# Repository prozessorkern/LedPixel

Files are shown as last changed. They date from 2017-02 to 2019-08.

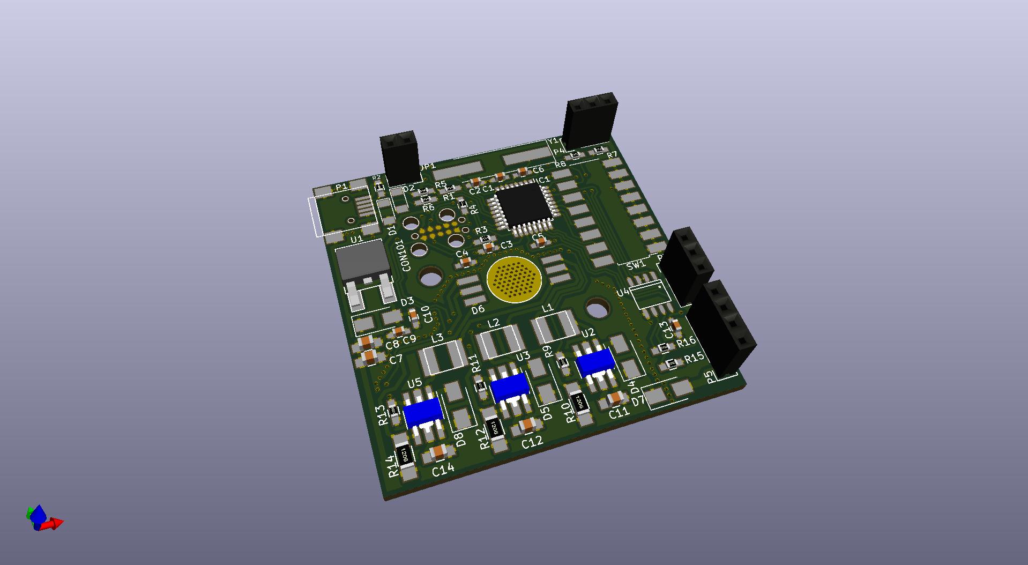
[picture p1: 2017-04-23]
atmega8/pcb/led_pixel/doc/led_pixel.jpg

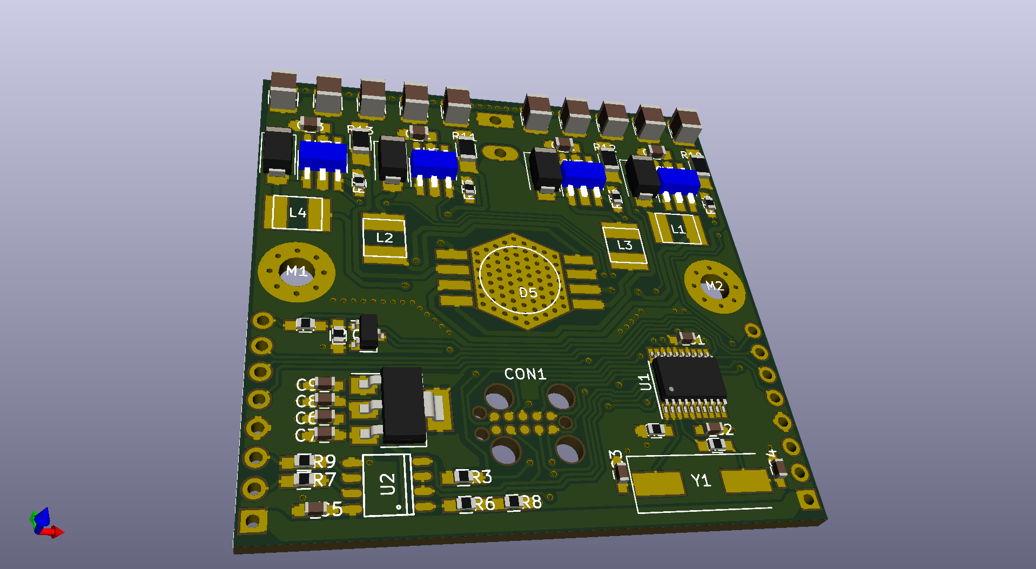
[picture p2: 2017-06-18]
stm32f030/pcb/led_pixel_stm32f030/doc/led_pixel_stm32f030.png

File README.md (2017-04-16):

# LedPixel
Small devices to drive up to 10W RGB LEDs by DMX
There might be a possibility to use them als a LED Wall/Display with extreme high power :)

## there might be several versions of the pcb (and Firmware)
* a dev board version with an ATmega8 with USB Bootloader, a dip Switch and some additional Interfaces
* a RGBW version with 4 LED Drivers an a STM32 Controller with 16 bit PWM, an faster RS485 than DMX and an additional SPI Interface for addressing multiple devices
* a board for an external LED

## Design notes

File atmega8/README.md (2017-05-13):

# LedPixel atmega8

* a dev board version with an ATmega8 with USB Bootloader, a dip Switch and some additional Interfaces
* designed to drive a 10W RGB LED with a single supply and DMX

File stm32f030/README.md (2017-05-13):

# LedPixel stm32f030

* a more powerful version with 4 chanels for RGBW LEDs
* designed with a backplane bus for dynamic adressing of multiple devices
* capable of 16 bit pwm for better resolution

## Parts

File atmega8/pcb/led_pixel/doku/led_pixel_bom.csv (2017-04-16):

ID | Bezeichner | Gehäuse | Stückzahl | Bezeichnung | Anbieter und Ref.
1 | Y1 | Crystal_SMD_HC49-SD_HandSoldering | 1 | CRYSTAL
2 | L3,L2,L1 | Choke_SMD_4.5x4x3.2 | 3 | 68u
3 | D6 | LED_SMD_RGB_3W | 1 | LED_RGB
4 | REF**,REF** | MountingHole_3.2mm_M3_DIN965 | 2 | MountingHole_3.2mm_M3_DIN965
5 | REF*** | OSHW-Logo2_7.3x6mm_Copper | 1 | OSHW-Logo2_7.3x6mm_Copper
6 | REF*** | WEEE-Logo_4.2x6mm_SilkScreen | 1 | WEEE-Logo_4.2x6mm_SilkScreen
7 | REF** | Symbol_KiCAD-Logo_CopperAndSilkScreenTop | 1 | KiCAD Logo
8 | G*** | Shimatta_SolderMask | 1 | LOGO
9 | C1,C2 | C_0603_HandSoldering | 2 | 22p
10 | C3,C10 | C_0603_HandSoldering | 2 | 1u
11 | C4,C5,C6,C9,C13 | C_0603_HandSoldering | 5 | 100n
12 | C7 | C_0805_HandSoldering | 1 | 1u
13 | C8,C11,C12,C14 | C_0805_HandSoldering | 4 | 100n
14 | IC1 | TQFP-32_7x7mm_Pitch0.8mm | 1 | ATMEGA8-AI
15 | P1 | USB_Mini-B | 1 | USB_OTG
16 | R1,R9,R11,R13,R4 | R_0603_HandSoldering | 5 | 10k
17 | R2 | R_0603_HandSoldering | 1 | 2k2
18 | R3,R7,R8,R15,R16 | R_0603_HandSoldering | 5 | 10
19 | R5,R6 | R_0603_HandSoldering | 2 | 39
20 | R10,R12,R14 | R_1206_HandSoldering | 3 | 0.33
21 | U1 | TO-252-2Lead | 1 | MC78M05CDT
22 | JP1 | Socket_Strip_Straight_1x02 | 1 | Bootloader
23 | P3,P4 | Socket_Strip_Straight_1x03 | 2 | CONN_01X03
24 | P5 | Socket_Strip_Straight_1x04 | 1 | CONN_01X04
25 | U2,U3,U5 | SOT89-5_Housing_Handsoldering | 3 | PT4115
26 | U4 | SO-8 | 1 | SN75176
27 | SW1 | SW_DIP_x8_SMD_2.54 | 1 | SW_DIP_x08
28 | D1,D2 | D_MiniMELF_Standard | 2 | 3V3
29 | D3,D4,D5,D7,D8 | D_SMA_Standard | 5 | SS310
30 | CON101 | TC2050-IDC | 1 | 10PIN_ISP_AVR

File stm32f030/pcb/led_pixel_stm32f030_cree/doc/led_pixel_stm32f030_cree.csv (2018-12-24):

ID | Bezeichner | Gehäuse | Stückzahl | Bezeichnung | Anbieter und Referenz
1 | CON1 | TC2050-IDC | 1 | 10PIN_JTAG_SWD
2 | G*** | Shimatta_SolderMask | 1 | LOGO
3 | REF*** | ESD-Logo_8.9x8mm_SilkScreen | 1 | ESD-Logo_8.9x8mm_SilkScreen
4 | REF*** | WEEE-Logo_4.2x6mm_SilkScreen | 1 | WEEE-Logo_4.2x6mm_SilkScreen
5 | REF** | Symbol_KiCAD-Logo_CopperAndSilkScreenTop | 1 | KiCAD Logo
6 | L4,L1,L2,L3 | Choke_SMD_4.5x4x3.2 | 4 | 68u
7 | Q1 | SOT-23 | 1 | BC107
8 | C5,C1,C2,C7,C8 | C_0603_HandSoldering | 5 | 100n
9 | C3,C4 | C_0603_HandSoldering | 2 | 20p
10 | C6,C9 | C_0603_HandSoldering | 2 | 1u
11 | C10,C11,C12,C13 | C_0805_HandSoldering | 4 | 100n
12 | D1,D2,D3,D4 | D_SMA_Standard | 4 | SS310
13 | J1 | AK300-2 | 1 | Screw_Terminal_01x02
14 | R1,R3,R5,R8,R14,R15,R16,R17 | R_0603_HandSoldering | 8 | 10k
15 | R4 | R_0603_HandSoldering | 1 | 1k
16 | R6 | R_0603_HandSoldering | 1 | 6k8
17 | R7,R9 | R_0603_HandSoldering | 2 | 10
18 | R10,R11,R12,R13 | R_1206_HandSoldering | 4 | 0.33
19 | U1 | TSSOP-20_4.4x6.5mm_Pitch0.65mm | 1 | STM32F030F4Px
20 | U2 | SO-8 | 1 | SN75176
21 | U3 | SOT-223 | 1 | 1117-3.3
22 | U4,U5,U6,U7 | SOT89-5_Housing_Handsoldering | 4 | PT4115
23 | Y1 | Crystal_SMD_HC49-SD | 1 | 8MHz
24 | R2 | R_0603_HandSoldering | 1 | 220
25 | J2,J3 | Pin_Header_Straight_1x08_Pitch2.54mm | 2 | Conn_01x08
26 | C14,C15,C16,C17,C18,C19,C20,C21,C22,C23 | C_1210 | 10 | 10u 50V
27 | M1,M2 | MountingHole_3.2mm_M3_Pad_Via | 2 | mounting hole
28 | D5 | LED_SMD_CREE_XM-L_4Color | 1 | LED_RGBW_cree

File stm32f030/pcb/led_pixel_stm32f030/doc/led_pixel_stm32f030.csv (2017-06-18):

ID | Bezeichner | Gehäuse | Stückzahl | Bezeichnung | Anbieter und Ref.
1 | D5 | LED_SMD_RGBW_4W_ISOLATED | 1 | LED_RGBW
2 | CON1 | TC2050-IDC | 1 | 10PIN_JTAG_SWD
3 | G*** | Shimatta_SolderMask | 1 | LOGO
4 | REF*** | ESD-Logo_8.9x8mm_SilkScreen | 1 | ESD-Logo_8.9x8mm_SilkScreen
5 | REF*** | WEEE-Logo_4.2x6mm_SilkScreen | 1 | WEEE-Logo_4.2x6mm_SilkScreen
6 | REF** | Symbol_KiCAD-Logo_CopperAndSilkScreenTop | 1 | KiCAD Logo
7 | L4,L1,L2,L3 | Choke_SMD_4.5x4x3.2 | 4 | 68u
8 | Q1 | SOT-23 | 1 | BC107
9 | C5,C1,C2,C7,C8 | C_0603_HandSoldering | 5 | 100n
10 | C3,C4 | C_0603_HandSoldering | 2 | 20p
11 | C6,C9 | C_0603_HandSoldering | 2 | 1u
12 | C10,C11,C12,C13 | C_0805_HandSoldering | 4 | 100n
13 | D1,D2,D3,D4 | D_SMA_Standard | 4 | SS310
14 | J1 | AK300-2 | 1 | Screw_Terminal_1x02
15 | R1,R3,R5,R8,R14,R15,R16,R17 | R_0603_HandSoldering | 8 | 10k
16 | R4 | R_0603_HandSoldering | 1 | 1k
17 | R6 | R_0603_HandSoldering | 1 | 6k8
18 | R7,R9 | R_0603_HandSoldering | 2 | 10
19 | R10,R11,R12,R13 | R_1206_HandSoldering | 4 | 0.33
20 | U1 | TSSOP-20_4.4x6.5mm_Pitch0.65mm | 1 | STM32F030F4Px
21 | U2 | SO-8 | 1 | SN75176
22 | U3 | SOT-223 | 1 | 1117-3.3
23 | U4,U5,U6,U7 | SOT89-5_Housing_Handsoldering | 4 | PT4115
24 | Y1 | Crystal_SMD_HC49-SD | 1 | 8MHz
25 | R2 | R_0603_HandSoldering | 1 | 220
26 | J2,J3 | Pin_Header_Straight_1x08_Pitch2.54mm | 2 | CONN_01X08
27 | C14,C15,C16,C17,C18,C19,C20,C21,C22,C23 | C_1210 | 10 | 10u 50V
28 | M1,M2 | MountingHole_3.2mm_M3_Pad_Via | 2 | mounting hole

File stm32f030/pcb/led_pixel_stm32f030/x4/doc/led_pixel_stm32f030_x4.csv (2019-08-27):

Id | Designator | Package | Quantity | Designation | Supplier and ref
1 | C19,C18,C17,C16,C15,C14,C23,C22,C21,C20,C19,C18,C17,C16,C15,C14,C23,C22,C21,C20,C19,C18,C17,C16,C15,C14,C23,C22,C21,C20,C14,C15,C16,C17,C18,C19,C20,C21,C22,C23 | C_1210 | 40 | 10u 50V
2 | D5,D5,D5,D5 | LED_SMD_RGBW_4W_ISOLATED | 4 | LED_RGBW
3 | C11,C10,C12,C13,C11,C10,C12,C13,C11,C10,C12,C13,C10,C11,C12,C13 | C_0805_HandSoldering | 16 | 100n
4 | Q1,Q1,Q1,Q1 | SOT-23 | 4 | BC107
5 | C9,C6,C9,C6,C9,C6,C6,C9 | C_0603_HandSoldering | 8 | 1u
6 | M2,M1,M2,M1,M2,M1,M1,M2 | MountingHole_3.2mm_M3_Pad_Via | 8 | mounting hole
7 | R15,R5,R17,R1,R8,R16,R14,R3,R15,R5,R17,R1,R8,R16,R14,R3,R15,R5,R17,R1,R8,R16,R14,R3,R1,R3,R5,R8,R14,R15,R16,R17 | R_0603_HandSoldering | 32 | 10k
8 | D1,D2,D3,D4,D1,D2,D3,D4,D1,D2,D3,D4,D1,D2,D3,D4 | D_SMA_Standard | 16 | SS310
9 | L3,L1,L2,L4,L3,L1,L2,L4,L3,L1,L2,L4,L4,L1,L2,L3 | Choke_SMD_4.5x4x3.2 | 16 | 68u
10 | R13,R10,R11,R12,R13,R10,R11,R12,R13,R10,R11,R12,R10,R11,R12,R13 | R_1206_HandSoldering | 16 | 0.33
11 | C1,C2,C8,C7,C5,C1,C2,C8,C7,C5,C1,C2,C8,C7,C5,C5,C1,C2,C7,C8 | C_0603_HandSoldering | 20 | 100n
12 | U3,U3,U3,U3 | SOT-223 | 4 | 1117-3.3
13 | U1,U1,U1,U1 | TSSOP-20_4.4x6.5mm_Pitch0.65mm | 4 | STM32F030F4Px
14 | U4,U6,U5,U7,U4,U6,U5,U7,U4,U6,U5,U7,U4,U5,U6,U7 | SOT89-5_Housing_Handsoldering | 16 | PT4115
15 | R6,R6,R6,R6 | R_0603_HandSoldering | 4 | 6k8
16 | Y1,Y1,Y1,Y1 | Crystal_SMD_HC49-SD | 4 | 8MHz
17 | C3,C4,C3,C4,C3,C4,C3,C4 | C_0603_HandSoldering | 8 | 20p
18 | R4,R4,R4,R4 | R_0603_HandSoldering | 4 | 1k
19 | R7,R9,R7,R9,R7,R9,R7,R9 | R_0603_HandSoldering | 8 | 10
20 | J2,J3,J2,J3,J2,J3,J2,J3 | Pin_Header_Straight_1x08_Pitch2.54mm | 8 | CONN_01X08
21 | U2,U2,U2,U2 | SO-8 | 4 | SN75176
22 | R2,R2,R2,R2 | R_0603_HandSoldering | 4 | 220
23 | J1,J1,J1,J1 | AK300-2 | 4 | Screw_Terminal_1x02
24 | CON1,CON1,CON1,CON1 | TC2050-IDC | 4 | 10PIN_JTAG_SWD
25 | G*** | Shimatta_SolderMask | 1 | LOGO
26 | REF*** | ESD-Logo_8.9x8mm_SilkScreen | 1 | ESD-Logo_8.9x8mm_SilkScreen
27 | REF*** | WEEE-Logo_4.2x6mm_SilkScreen | 1 | WEEE-Logo_4.2x6mm_SilkScreen
28 | REF** | Symbol_KiCAD-Logo_CopperAndSilkScreenTop | 1 | KiCAD Logo

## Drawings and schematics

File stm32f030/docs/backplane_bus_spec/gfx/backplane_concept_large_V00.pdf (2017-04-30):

## large scale

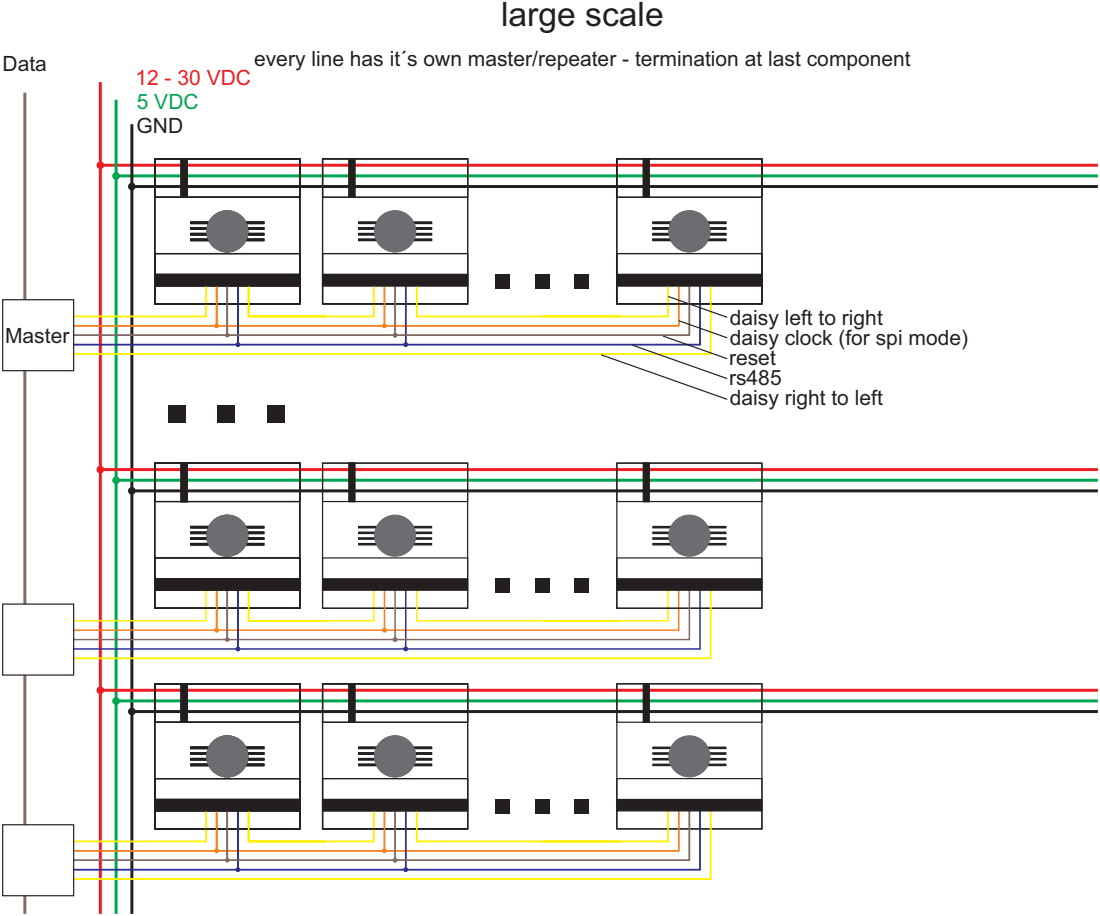
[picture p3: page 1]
12 - 30 VDC 5 VDC GND; Data; Master

every line has it´s own master/repeater - termination at last component

daisy left to right
daisy clock (for spi mode)
reset
daisy right to left

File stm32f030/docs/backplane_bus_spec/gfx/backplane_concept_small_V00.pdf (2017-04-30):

## small scale

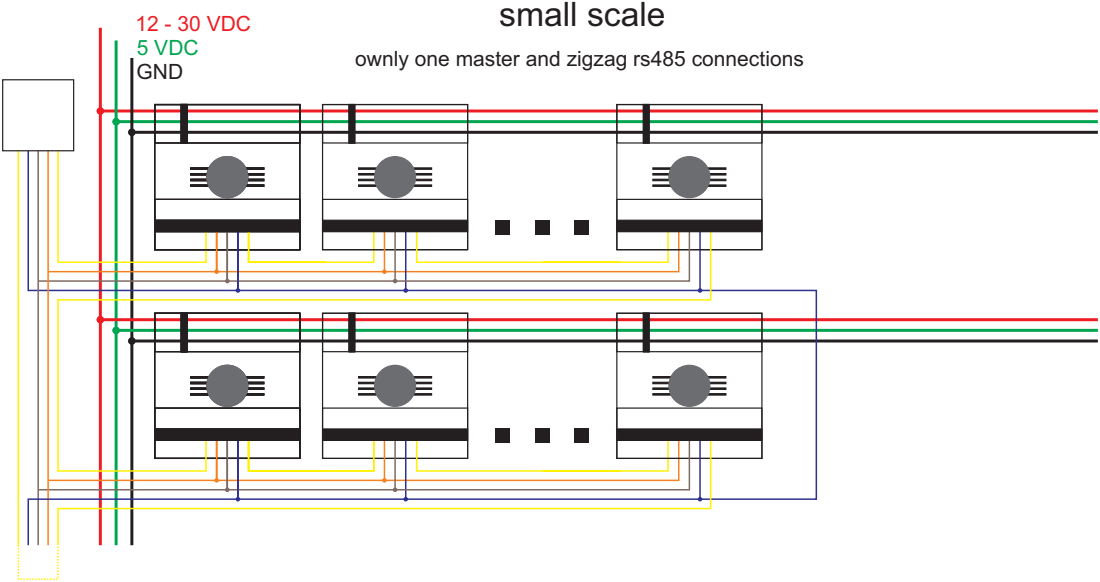
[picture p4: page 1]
12 - 30 VDC 5 VDC GND

ownly one master and zigzag rs485 connections

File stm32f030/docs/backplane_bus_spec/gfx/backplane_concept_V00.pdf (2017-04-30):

## large scale

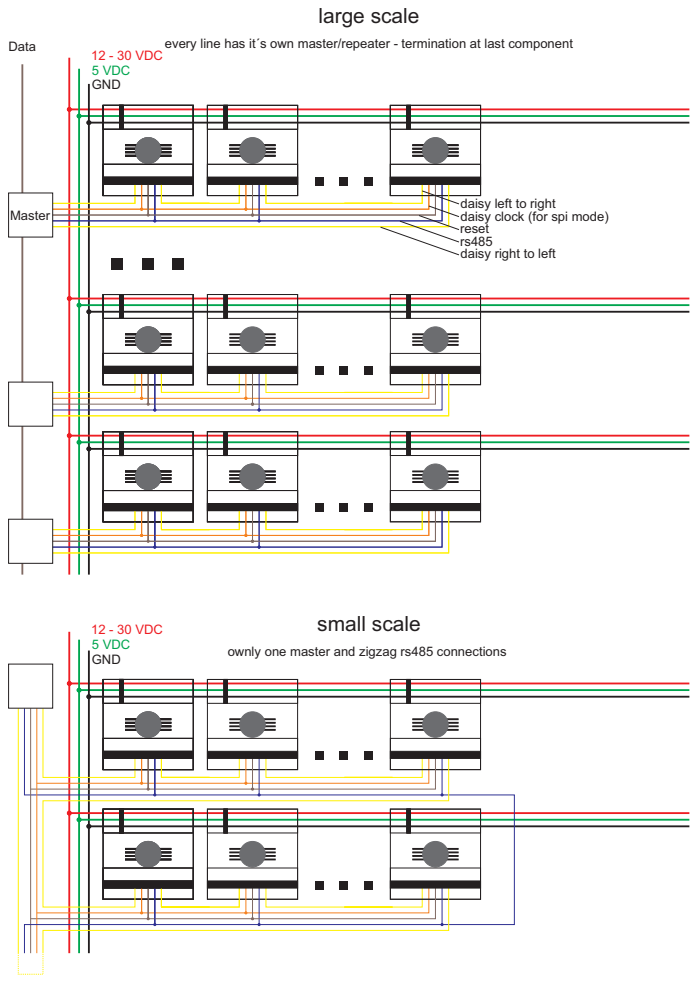
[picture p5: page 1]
12 - 30 VDC 5 VDC GND; Data; small scale; Master

every line has it´s own master/repeater - termination at last component

daisy left to right
daisy clock (for spi mode)
reset
daisy right to left

ownly one master and zigzag rs485 connections

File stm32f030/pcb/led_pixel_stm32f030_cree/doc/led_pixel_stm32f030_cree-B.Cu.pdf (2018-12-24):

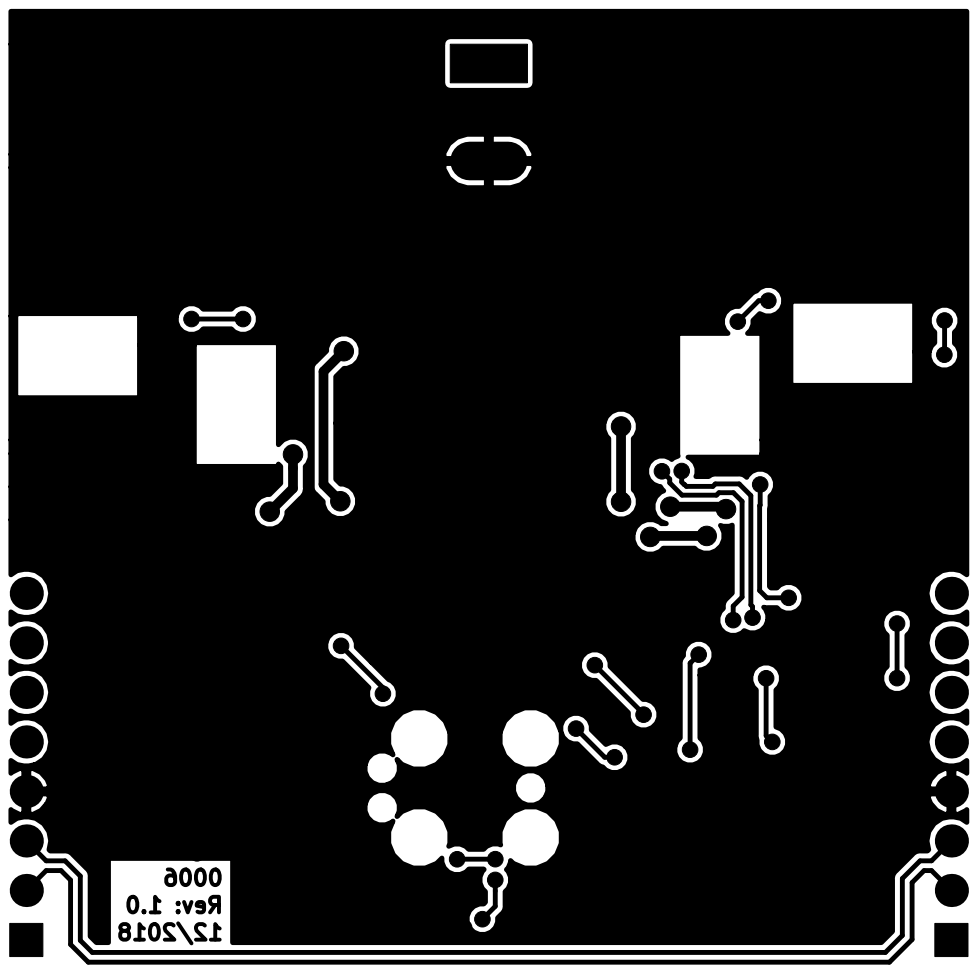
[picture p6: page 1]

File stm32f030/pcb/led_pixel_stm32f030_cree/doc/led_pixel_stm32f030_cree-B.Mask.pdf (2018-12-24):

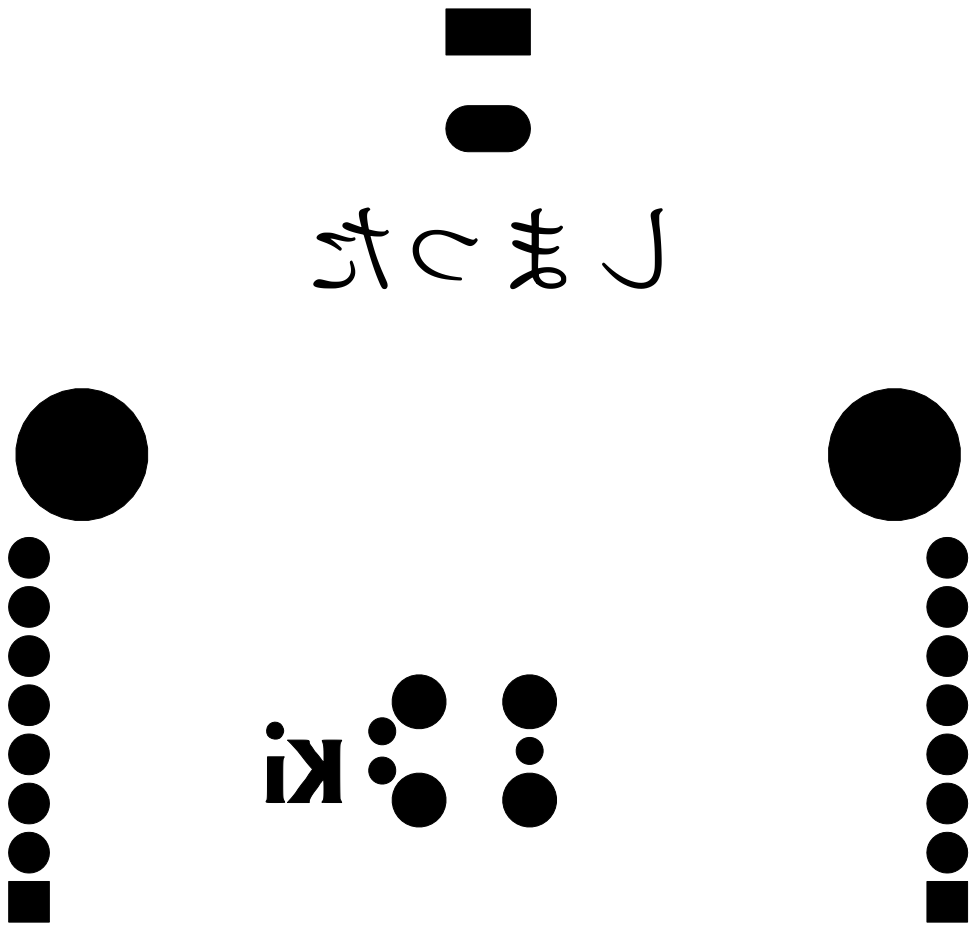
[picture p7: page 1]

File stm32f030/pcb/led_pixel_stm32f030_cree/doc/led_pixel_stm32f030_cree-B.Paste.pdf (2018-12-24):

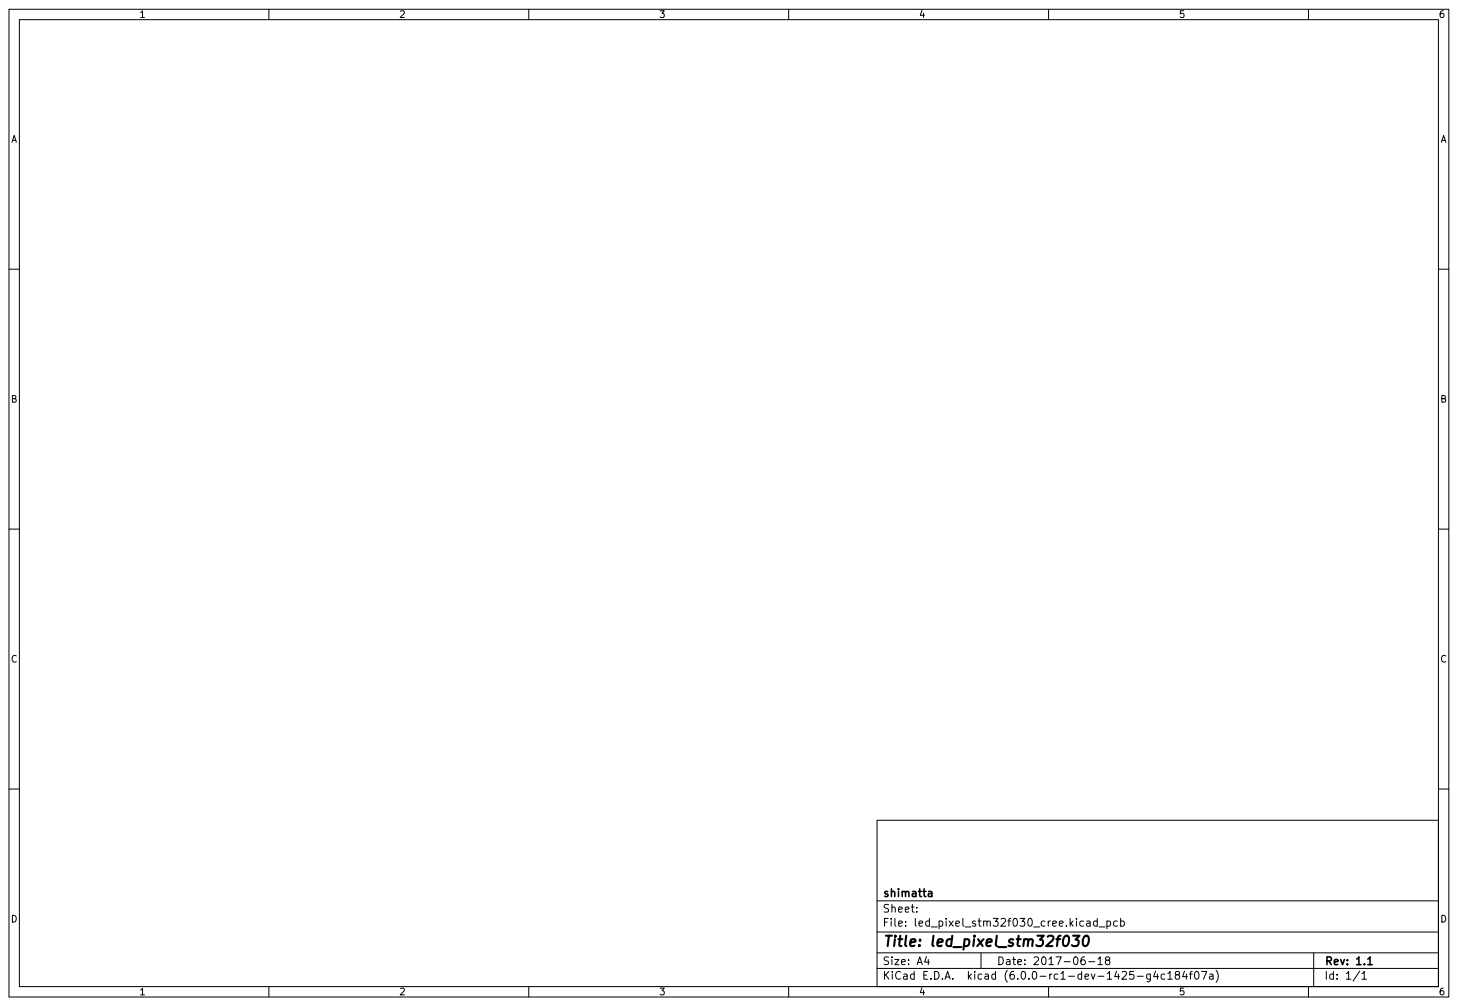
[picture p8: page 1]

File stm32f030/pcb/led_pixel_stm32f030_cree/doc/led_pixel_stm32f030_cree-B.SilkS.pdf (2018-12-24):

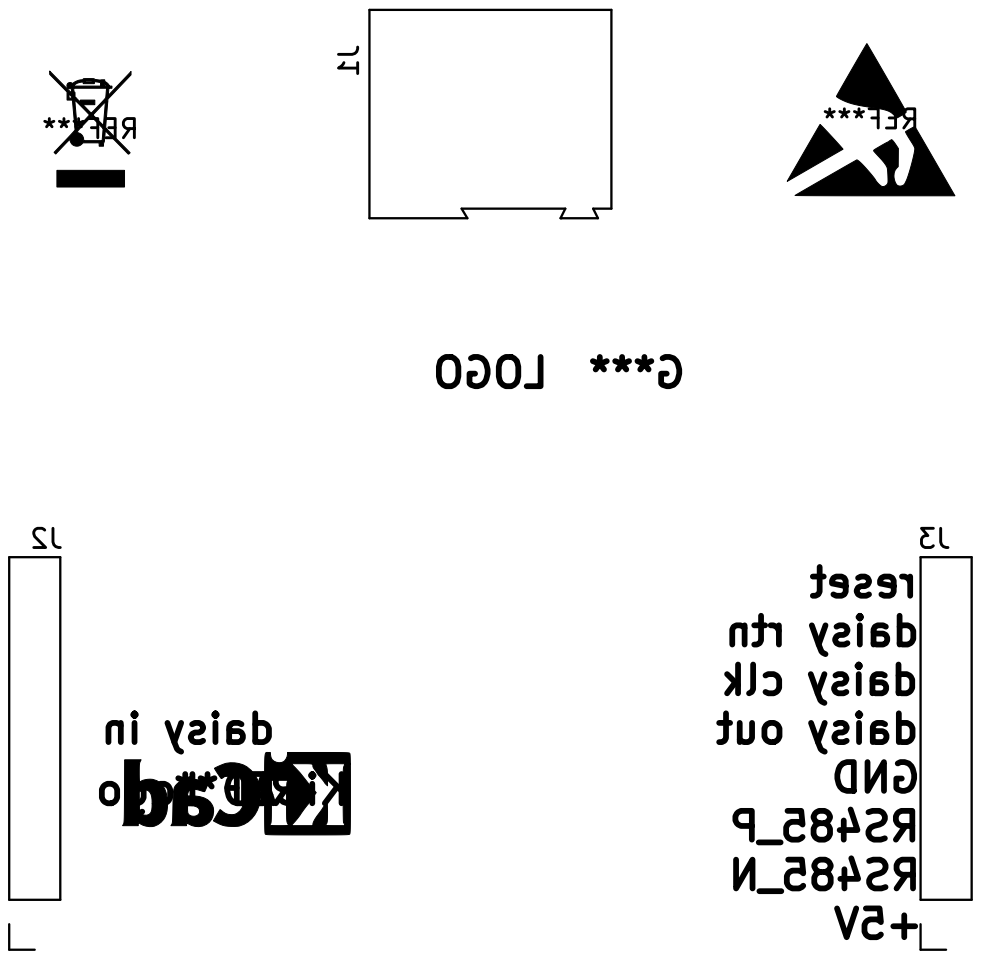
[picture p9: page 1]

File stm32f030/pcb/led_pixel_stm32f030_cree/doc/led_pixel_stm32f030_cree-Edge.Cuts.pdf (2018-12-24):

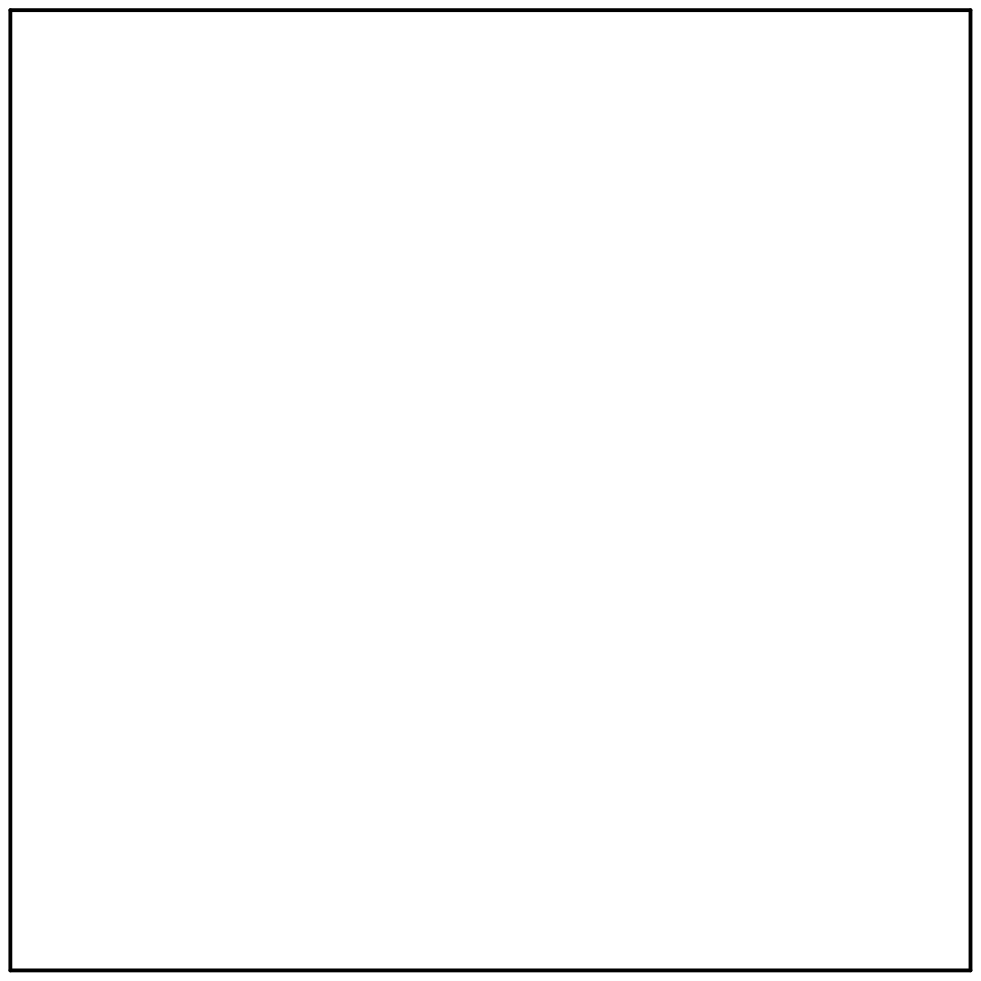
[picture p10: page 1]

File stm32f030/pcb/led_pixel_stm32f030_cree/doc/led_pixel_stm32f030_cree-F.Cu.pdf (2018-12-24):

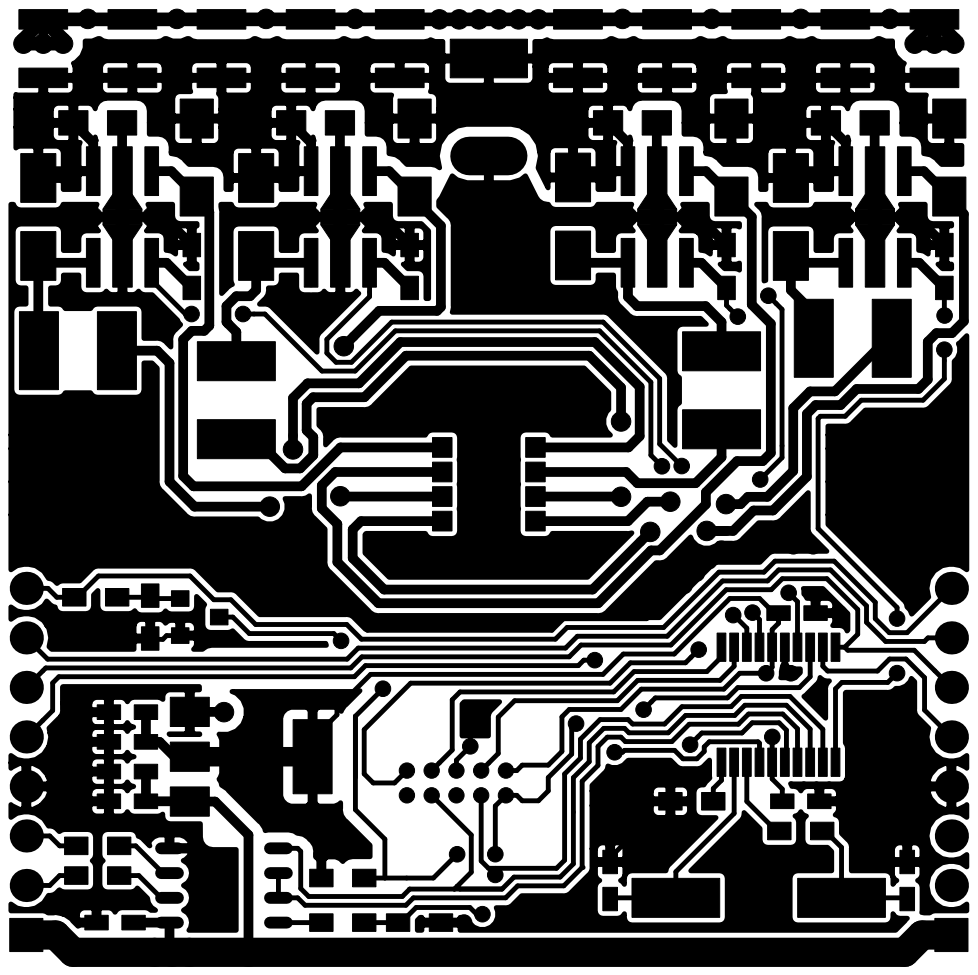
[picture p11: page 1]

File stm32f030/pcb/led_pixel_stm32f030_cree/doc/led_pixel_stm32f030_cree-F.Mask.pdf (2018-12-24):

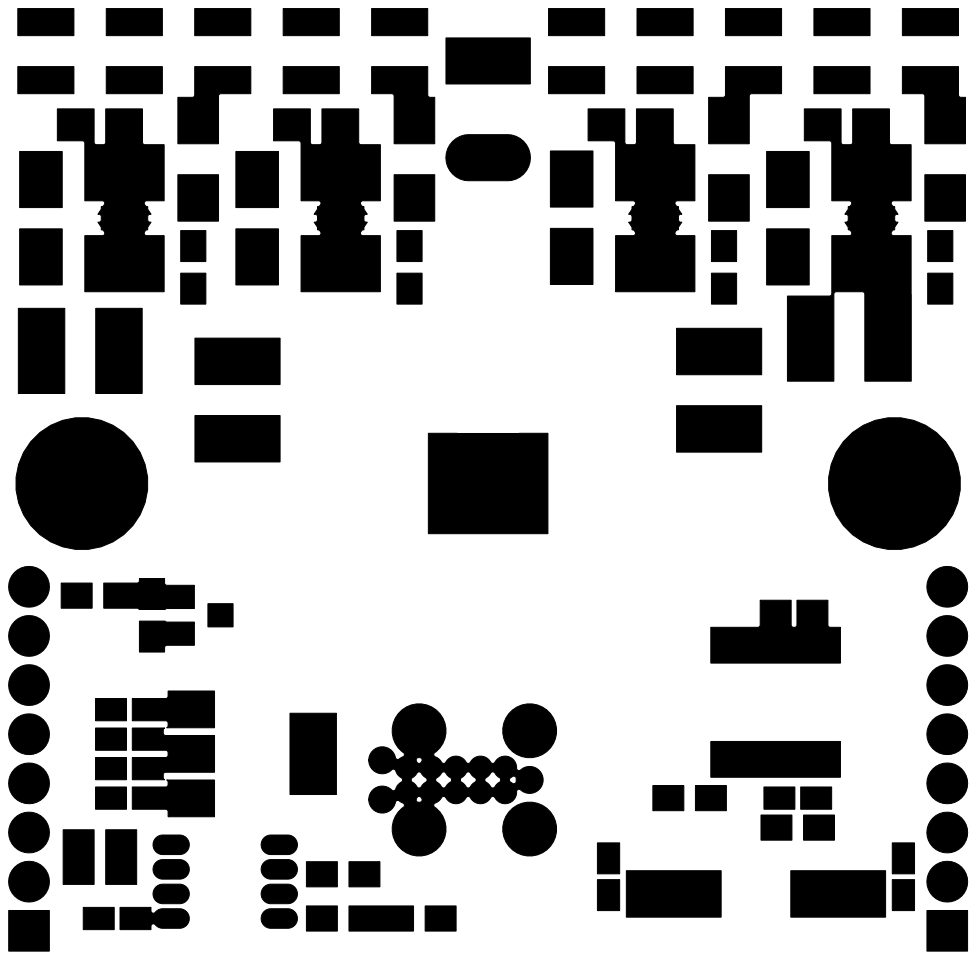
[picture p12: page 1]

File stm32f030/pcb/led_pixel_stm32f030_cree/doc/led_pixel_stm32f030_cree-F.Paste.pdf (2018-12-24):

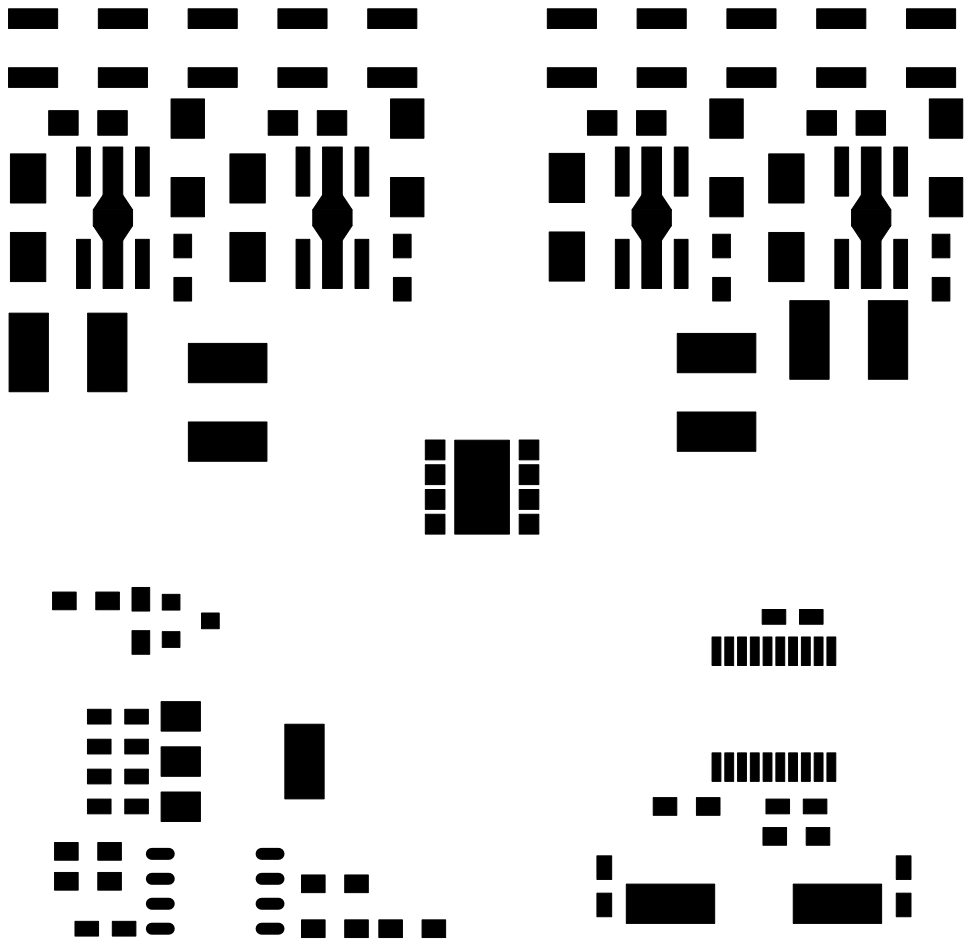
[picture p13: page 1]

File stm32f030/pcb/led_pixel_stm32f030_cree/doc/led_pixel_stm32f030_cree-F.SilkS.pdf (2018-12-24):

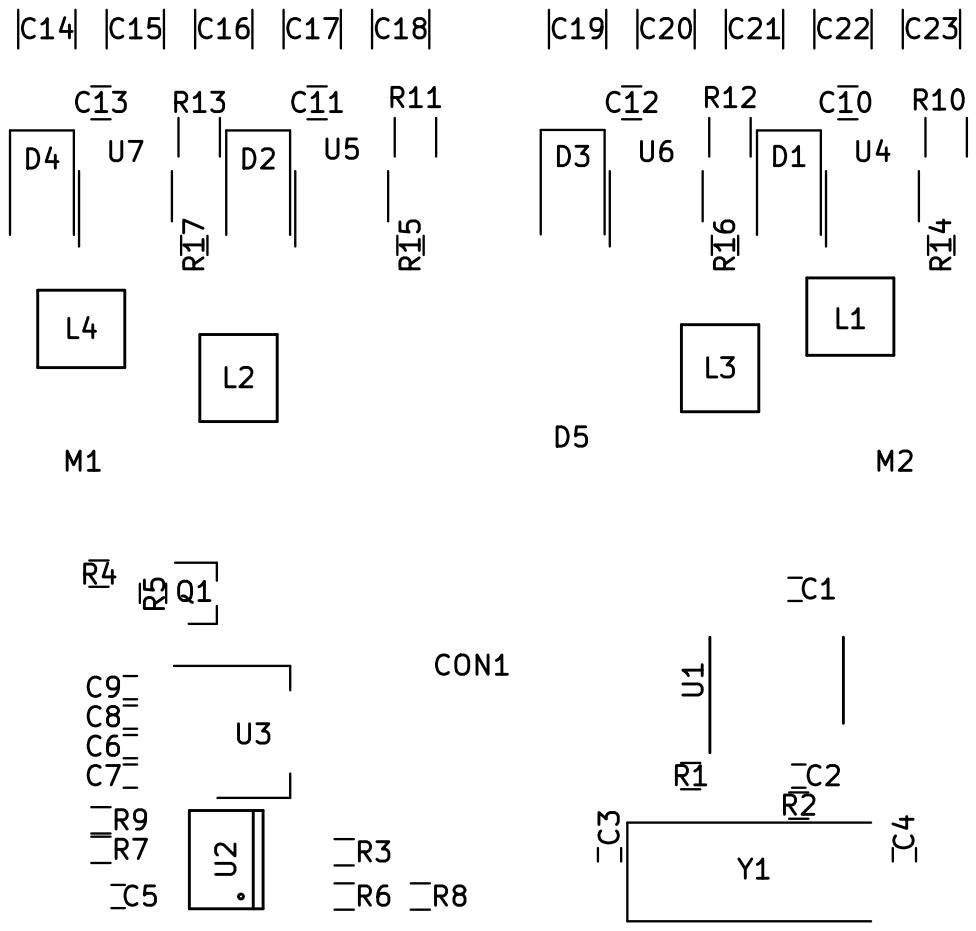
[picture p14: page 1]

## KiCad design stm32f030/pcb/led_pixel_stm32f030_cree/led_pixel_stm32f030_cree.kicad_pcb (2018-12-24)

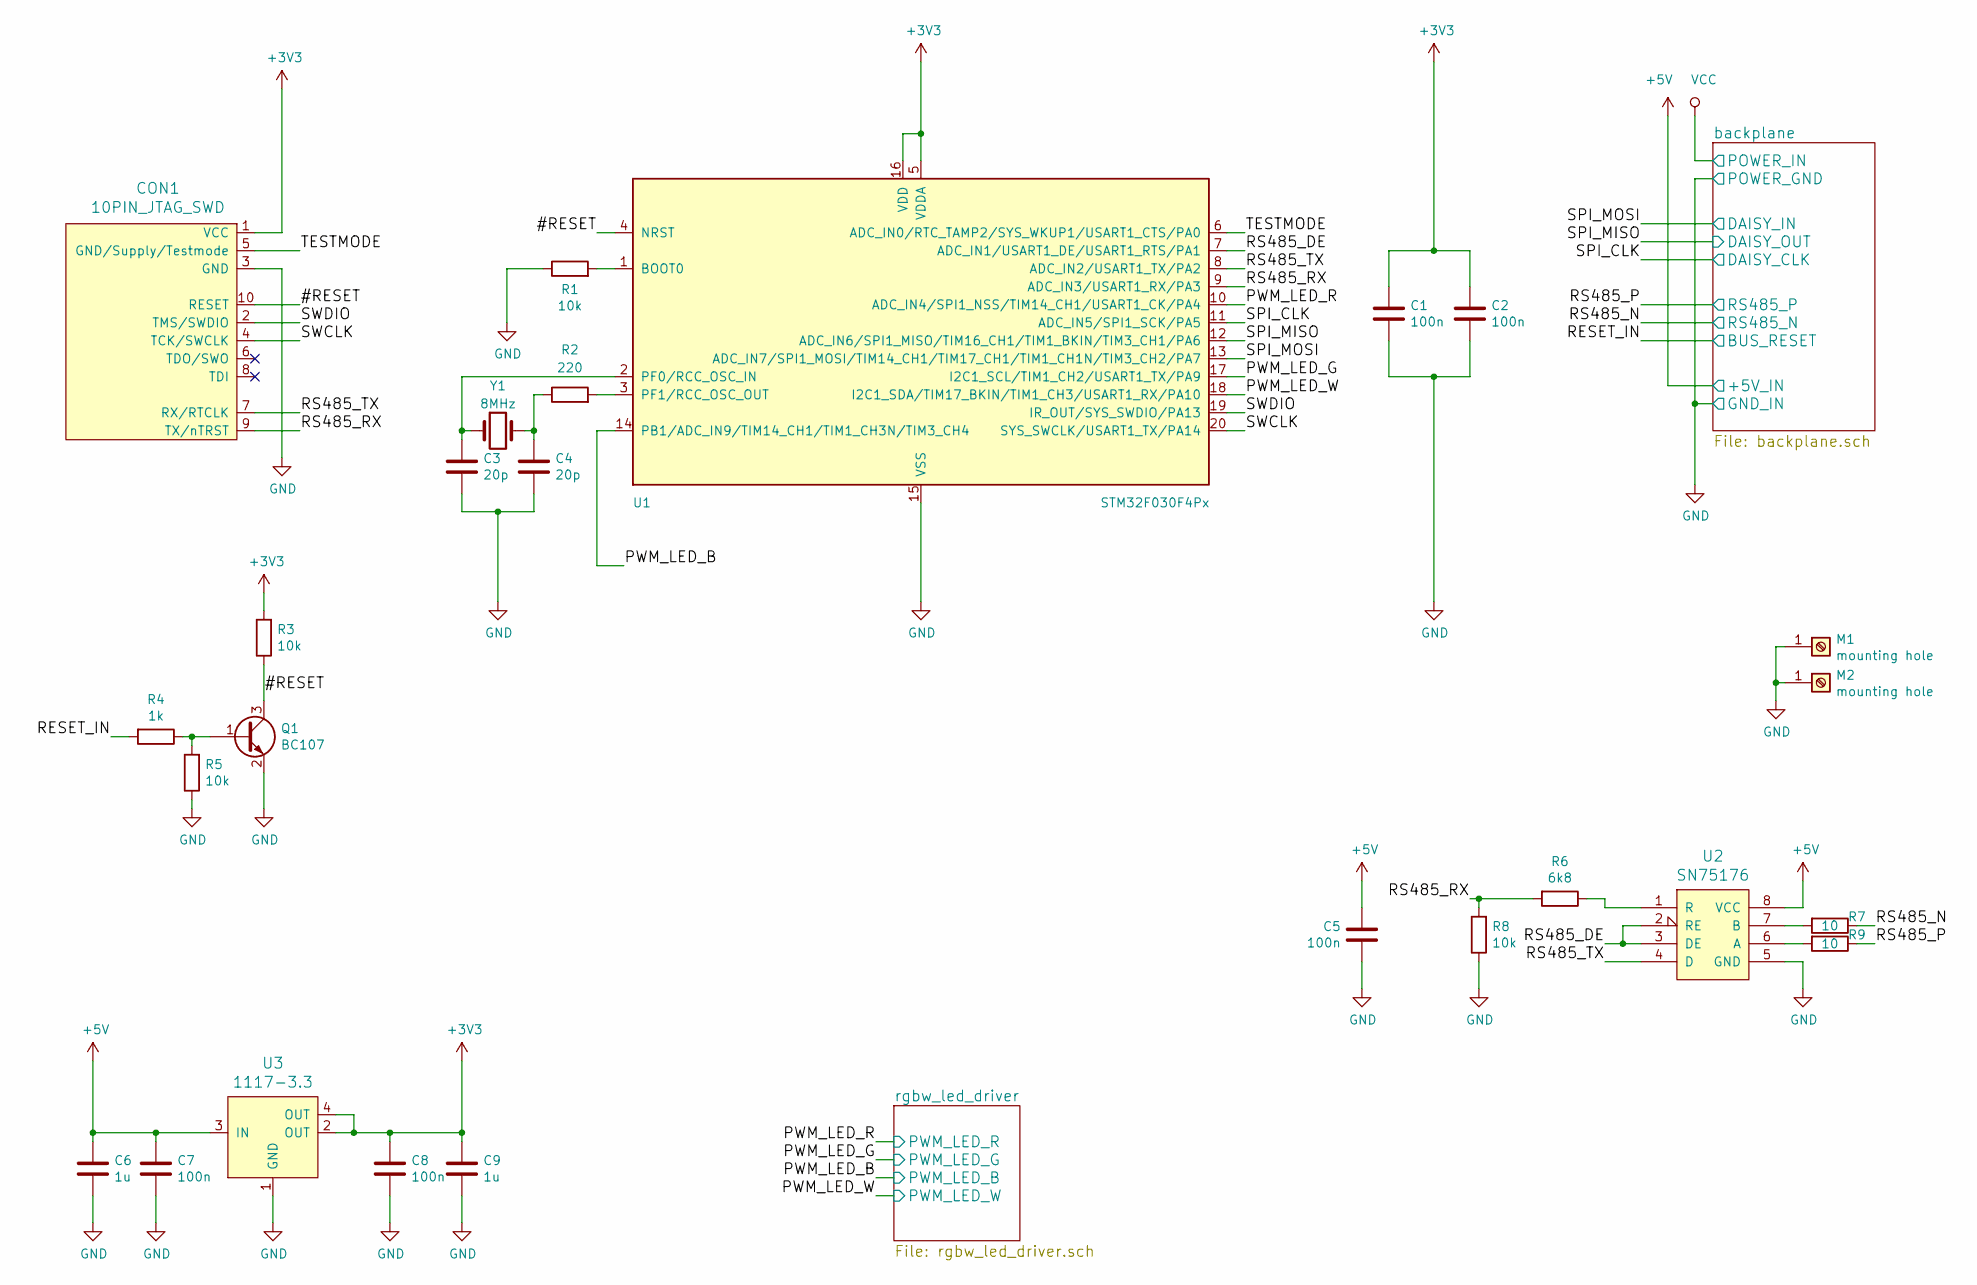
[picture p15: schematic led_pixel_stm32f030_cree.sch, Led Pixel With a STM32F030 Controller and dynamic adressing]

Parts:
C1, C2, C5, C7, C8: 100n; C_0603_HandSoldering
C3, C4: 20p; C_0603_HandSoldering
C6, C9: 1u; C_0603_HandSoldering
CON1: 10PIN_JTAG_SWD; TC2050-IDC
M1, M2: mounting hole; MountingHole_3.2mm_M3_Pad_Via
Q1: BC107; SOT-23
R1, R3, R5, R8: 10k; R_0603_HandSoldering
R2: 220; R_0603_HandSoldering
R4: 1k; R_0603_HandSoldering
R6: 6k8; R_0603_HandSoldering
R7, R9: 10; R_0603_HandSoldering
U1: STM32F030F4Px; TSSOP-20_4.4x6.5mm_Pitch0.65mm
U2: SN75176; SO-8
U3: 1117-3.3; SOT-223
Y1: 8MHz; Crystal_SMD_HC49-SD

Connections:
+3V3: C1.1, C2.1, C8.1, C9.1, CON1.1 (VCC), R3.2, U1.5 (VDDA), U1.16 (VDD), U3.2 (OUT), U3.4 (OUT)
+5V: C5.1, C6.1, C7.1, U2.8 (VCC), U3.3 (IN); also elsewhere on the board
/#RESET: CON1.10 (RESET), Q1.3 (C), R3.1, U1.4 (NRST)
/PWM_LED_B: U1.14 (PB1/ADC_IN9/TIM14_CH1/TIM1_CH3N/TIM3_CH4); also elsewhere on the board
/PWM_LED_G: U1.17 (I2C1_SCL/TIM1_CH2/USART1_TX/PA9); also elsewhere on the board
/PWM_LED_R: U1.10 (ADC_IN4/SPI1_NSS/TIM14_CH1/USART1_CK/PA4); also elsewhere on the board
/PWM_LED_W: U1.18 (I2C1_SDA/TIM17_BKIN/TIM1_CH3/USART1_RX/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); also elsewhere on the board
/RESET_IN: R4.2; also elsewhere on the board
/RS485_DE: U1.7 (ADC_IN1/USART1_DE/USART1_RTS/PA1), U2.2 (RE), U2.3 (DE)
/RS485_N: R7.1; also elsewhere on the board
/RS485_P: R9.1; also elsewhere on the board
/RS485_RX: CON1.9 (TX/nTRST), R6.2, R8.2, U1.9 (ADC_IN3/USART1_RX/PA3)
/RS485_TX: CON1.7 (RX/RTCLK), U1.8 (ADC_IN2/USART1_TX/PA2), U2.4 (D)
/SPI_CLK: U1.11 (ADC_IN5/SPI1_SCK/PA5); also elsewhere on the board
/SPI_MISO: U1.12 (ADC_IN6/SPI1_MISO/TIM16_CH1/TIM1_BKIN/T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); also elsewhere on the board
/SPI_MOSI: U1.13 (ADC_IN7/SPI1_MOSI/TIM14_CH1/TIM17_CH1/T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); also elsewhere on the board
/SWCLK: CON1.4 (TCK/SWCLK), U1.20 (SYS_SWCLK/USART1_TX/PA14)
/SWDIO: CON1.2 (TMS/SWDIO), U1.19 (IR_OUT/SYS_SWDIO/PA13)
/TESTMODE: CON1.5 (GND/Supply/Testmode), U1.6 (ADC_IN0/RTC_TAMP2/SYS_WKUP1/USART1_CTS/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)
GND: C1.2, C2.2, C3.2, C4.2, C5.2, C6.2, C7.2, C8.2, C9.2, CON1.3 (GND), M1.1, M2.1, Q1.2 (E), R1.1, R5.1, R8.1, U1.15 (VSS), U2.5 (GND), U3.1 (GND); also elsewhere on the board
unnamed: C3.1, U1.2 (PF0/RCC_OSC_IN), Y1.1
unnamed: C4.1, R2.1, Y1.2
unnamed: Q1.1 (B), R4.1, R5.2
unnamed: R1.2, U1.1 (BOOT0)
unnamed: R2.2, U1.3 (PF1/RCC_OSC_OUT)
unnamed: R6.1, U2.1 (R)
unnamed: R7.2, U2.7 (B)
unnamed: R9.2, U2.6 (A)

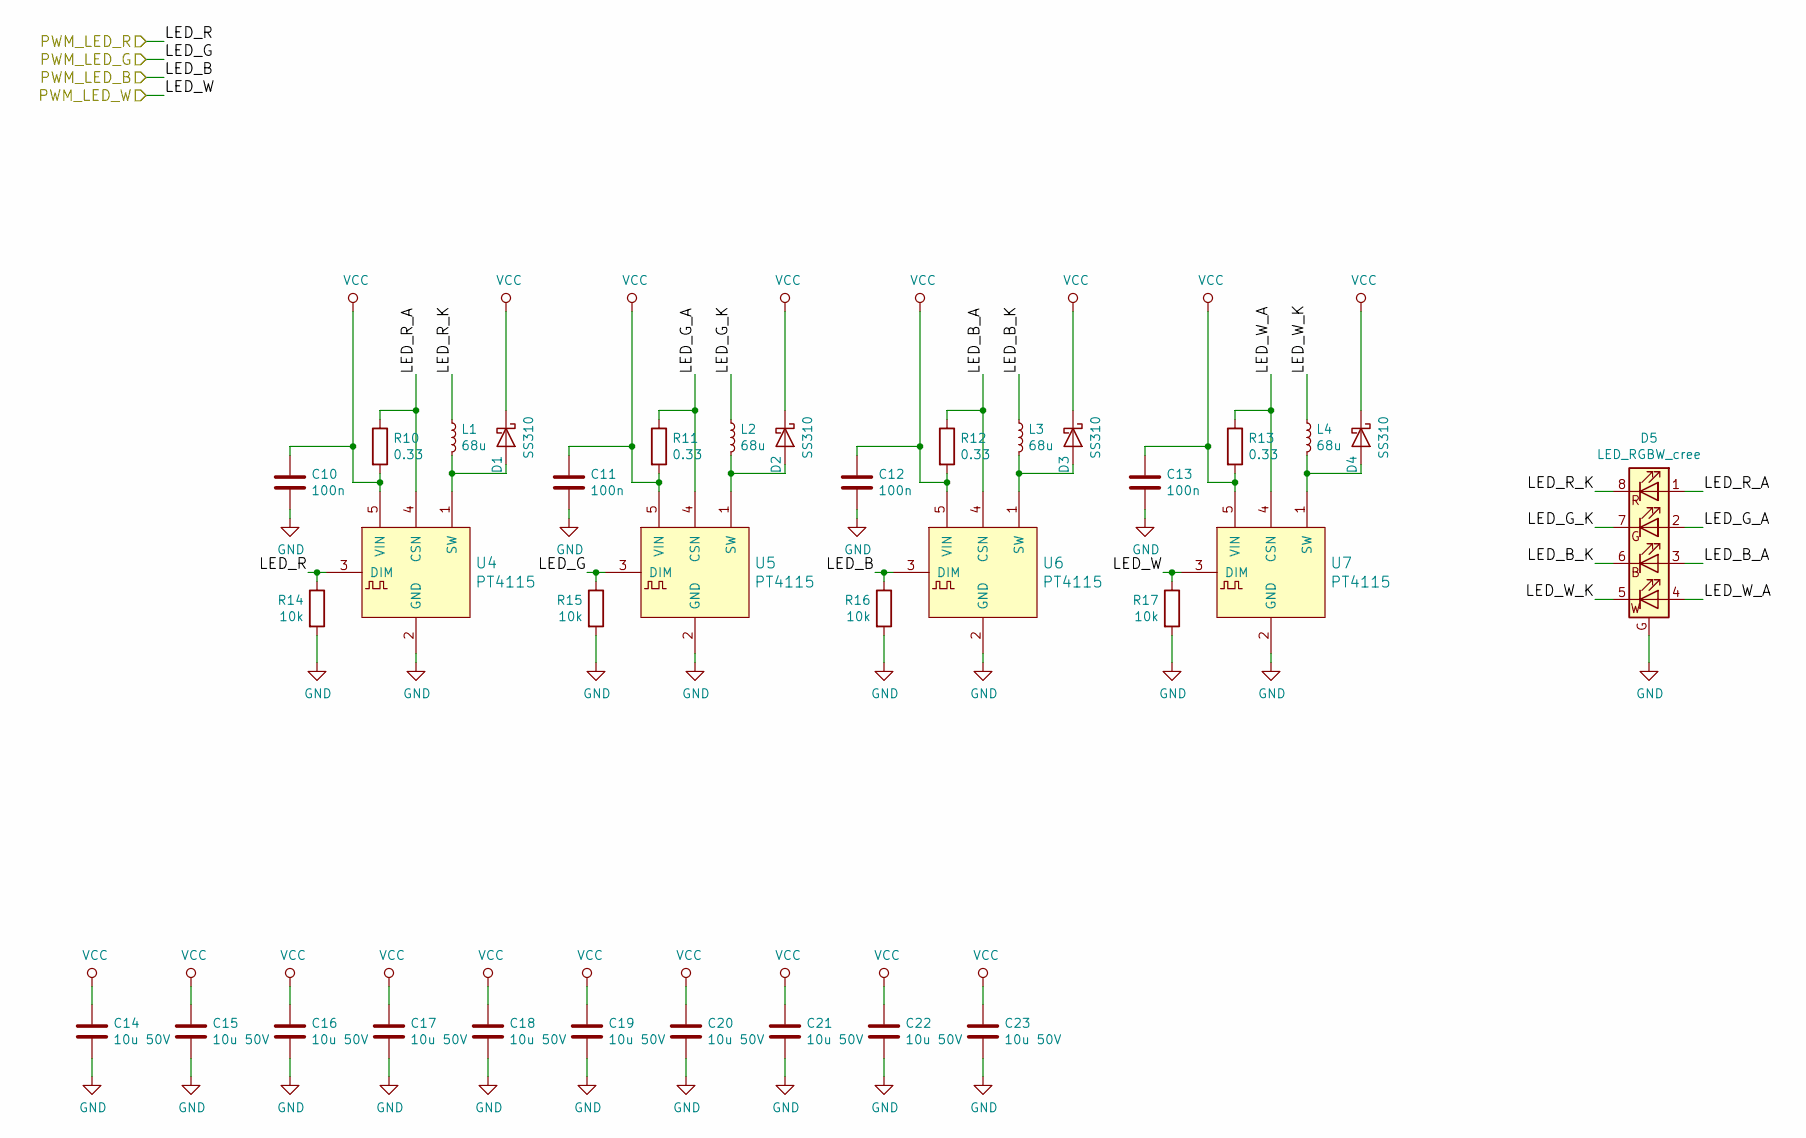
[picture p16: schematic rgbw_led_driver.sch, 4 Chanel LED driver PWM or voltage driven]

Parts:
C10, C11, C12, C13: 100n; C_0805_HandSoldering
C14, C15, C16, C17, C18, C19, C20, C21, C22, C23: 10u 50V; C_1210
D1, D2, D3, D4: SS310; D_SMA_Standard
D5: LED_RGBW_cree; LED_SMD_CREE_XM-L_4Color
L1, L2, L3, L4: 68u; Choke_SMD_4.5x4x3.2
R10, R11, R12, R13: 0.33; R_1206_HandSoldering
R14, R15, R16, R17: 10k; R_0603_HandSoldering
U4, U5, U6, U7: PT4115; SOT89-5_Housing_Handsoldering

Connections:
/PWM_LED_B: R16.1, U6.3 (DIM); also elsewhere on the board
/PWM_LED_G: R15.1, U5.3 (DIM); also elsewhere on the board
/PWM_LED_R: R14.1, U4.3 (DIM); also elsewhere on the board
/PWM_LED_W: R17.1, U7.3 (DIM); also elsewhere on the board
/rgbw_led_driver/LED_B_A: D5.3 (BK), R12.1, U6.4 (CSN)
/rgbw_led_driver/LED_B_K: D5.6 (BA), L3.1
/rgbw_led_driver/LED_G_A: D5.2 (GK), R11.1, U5.4 (CSN)
/rgbw_led_driver/LED_G_K: D5.7 (GA), L2.1
/rgbw_led_driver/LED_R_A: D5.1 (RK), R10.1, U4.4 (CSN)
/rgbw_led_driver/LED_R_K: D5.8 (RA), L1.1
/rgbw_led_driver/LED_W_A: D5.4 (WK), R13.1, U7.4 (CSN)
/rgbw_led_driver/LED_W_K: D5.5 (WA), L4.1
GND: C10.2, C11.2, C12.2, C13.2, C14.2, C15.2, C16.2, C17.2, C18.2, C19.2, C20.2, C21.2, C22.2, C23.2, D5.G (Thermal_Pad), R14.2, R15.2, R16.2, R17.2, U4.2 (GND), U5.2 (GND), U6.2 (GND), U7.2 (GND); also elsewhere on the board
unnamed: D1.2 (A), L1.2, U4.1 (SW)
unnamed: D2.2 (A), L2.2, U5.1 (SW)
unnamed: D3.2 (A), L3.2, U6.1 (SW)
unnamed: D4.2 (A), L4.2, U7.1 (SW)
VCC: C10.1, C11.1, C12.1, C13.1, C14.1, C15.1, C16.1, C17.1, C18.1, C19.1, C20.1, C21.1, C22.1, C23.1, D1.1 (K), D2.1 (K), D3.1 (K), D4.1 (K), R10.2, R11.2, R12.2, R13.2, U4.5 (VIN), U5.5 (VIN), U6.5 (VIN), U7.5 (VIN); also elsewhere on the board

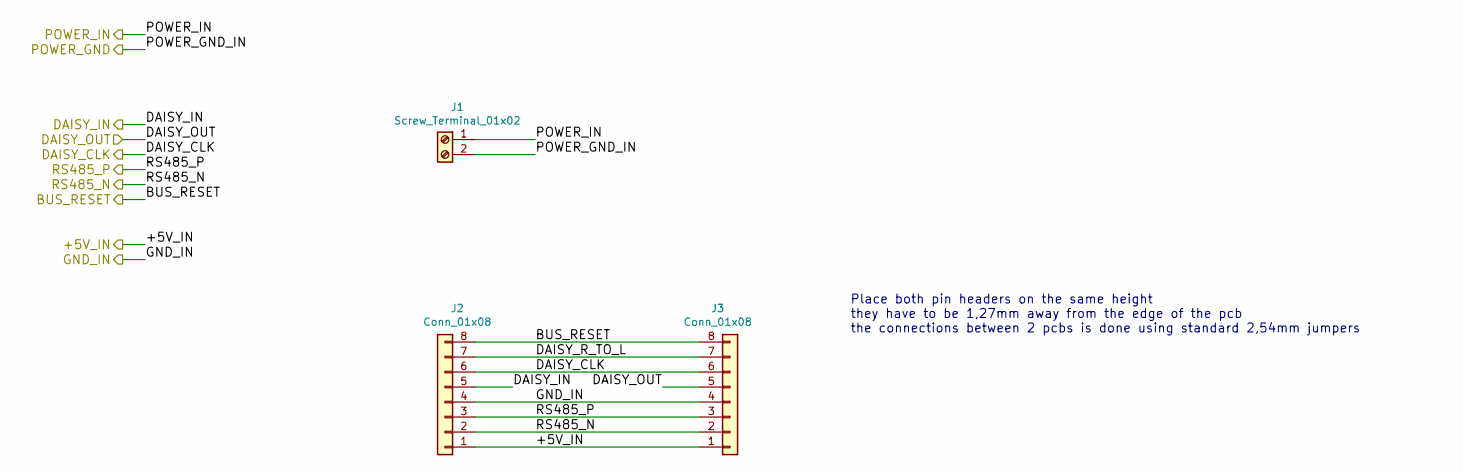
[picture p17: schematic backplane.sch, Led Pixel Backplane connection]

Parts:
J1: Screw_Terminal_01x02; AK300-2
J2, J3: Conn_01x08; Pin_Header_Straight_1x08_Pitch2.54mm

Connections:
+5V: J2.1, J3.1; also elsewhere on the board
/RESET_IN: J2.8, J3.8; also elsewhere on the board
/RS485_N: J2.2, J3.2; also elsewhere on the board
/RS485_P: J2.3, J3.3; also elsewhere on the board
/SPI_CLK: J2.6, J3.6; also elsewhere on the board
/SPI_MISO: J3.5; also elsewhere on the board
/SPI_MOSI: J2.5; also elsewhere on the board
/backplane/DAISY_R_TO_L: J2.7, J3.7
GND: J1.2, J2.4, J3.4; also elsewhere on the board
VCC: J1.1; also elsewhere on the board

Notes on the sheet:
Place both pin headers on the same height they have to be 1,27mm away from the edge of the pcb the connections between 2 pcbs is done using standard 2,54mm jumpers

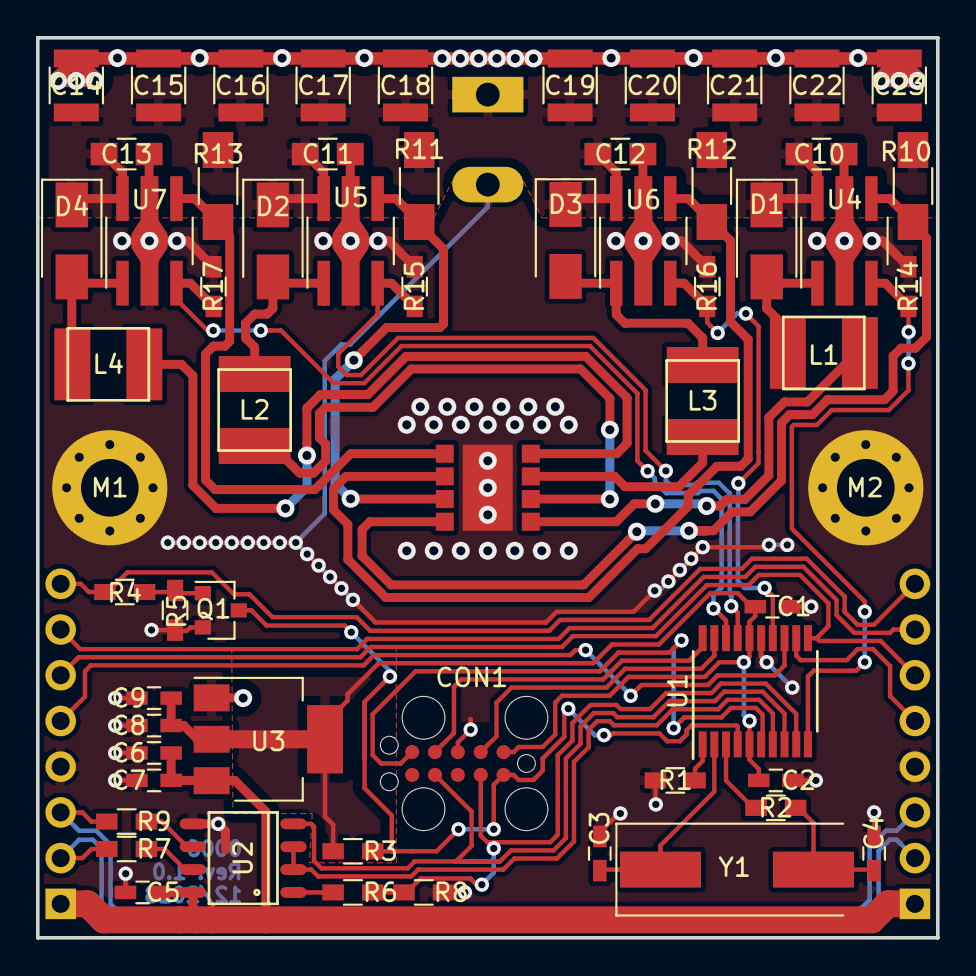
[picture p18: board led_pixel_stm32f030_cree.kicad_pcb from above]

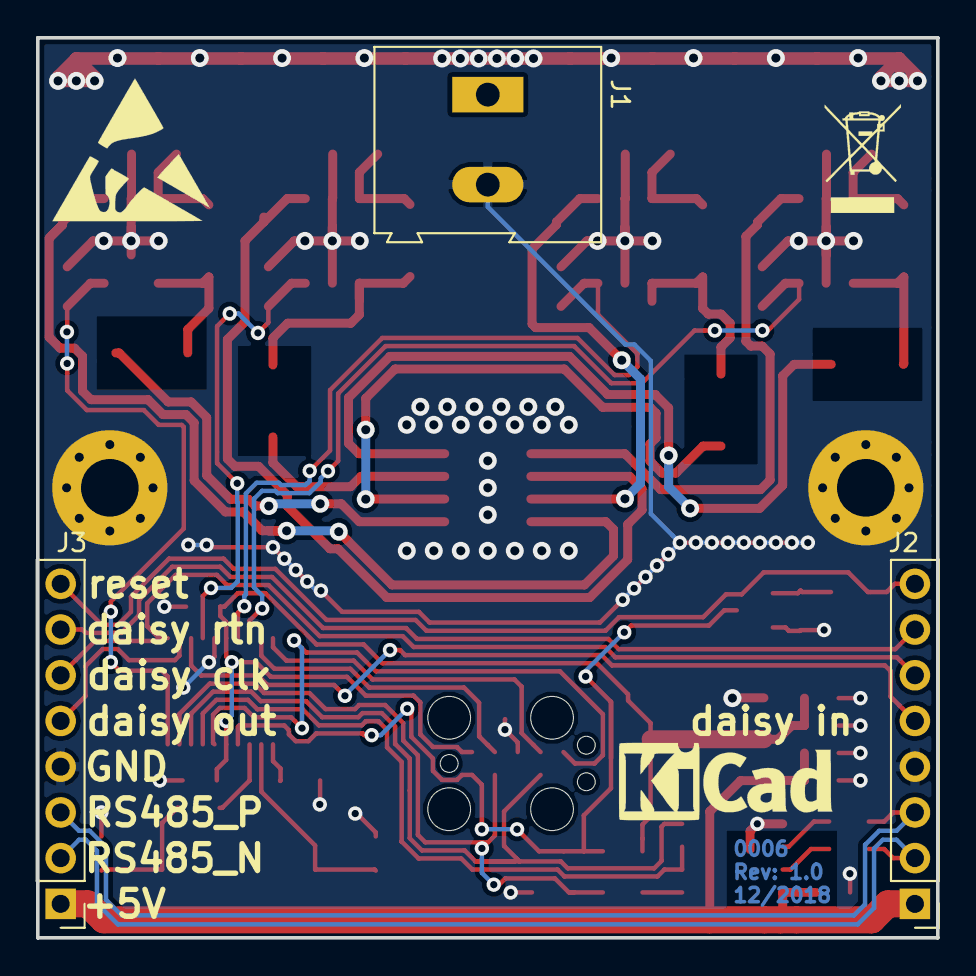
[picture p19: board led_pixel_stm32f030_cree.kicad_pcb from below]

Board: 2 copper layers, 50.0 x 50.0 mm, 64 parts (3 on the bottom side), 42 nets.

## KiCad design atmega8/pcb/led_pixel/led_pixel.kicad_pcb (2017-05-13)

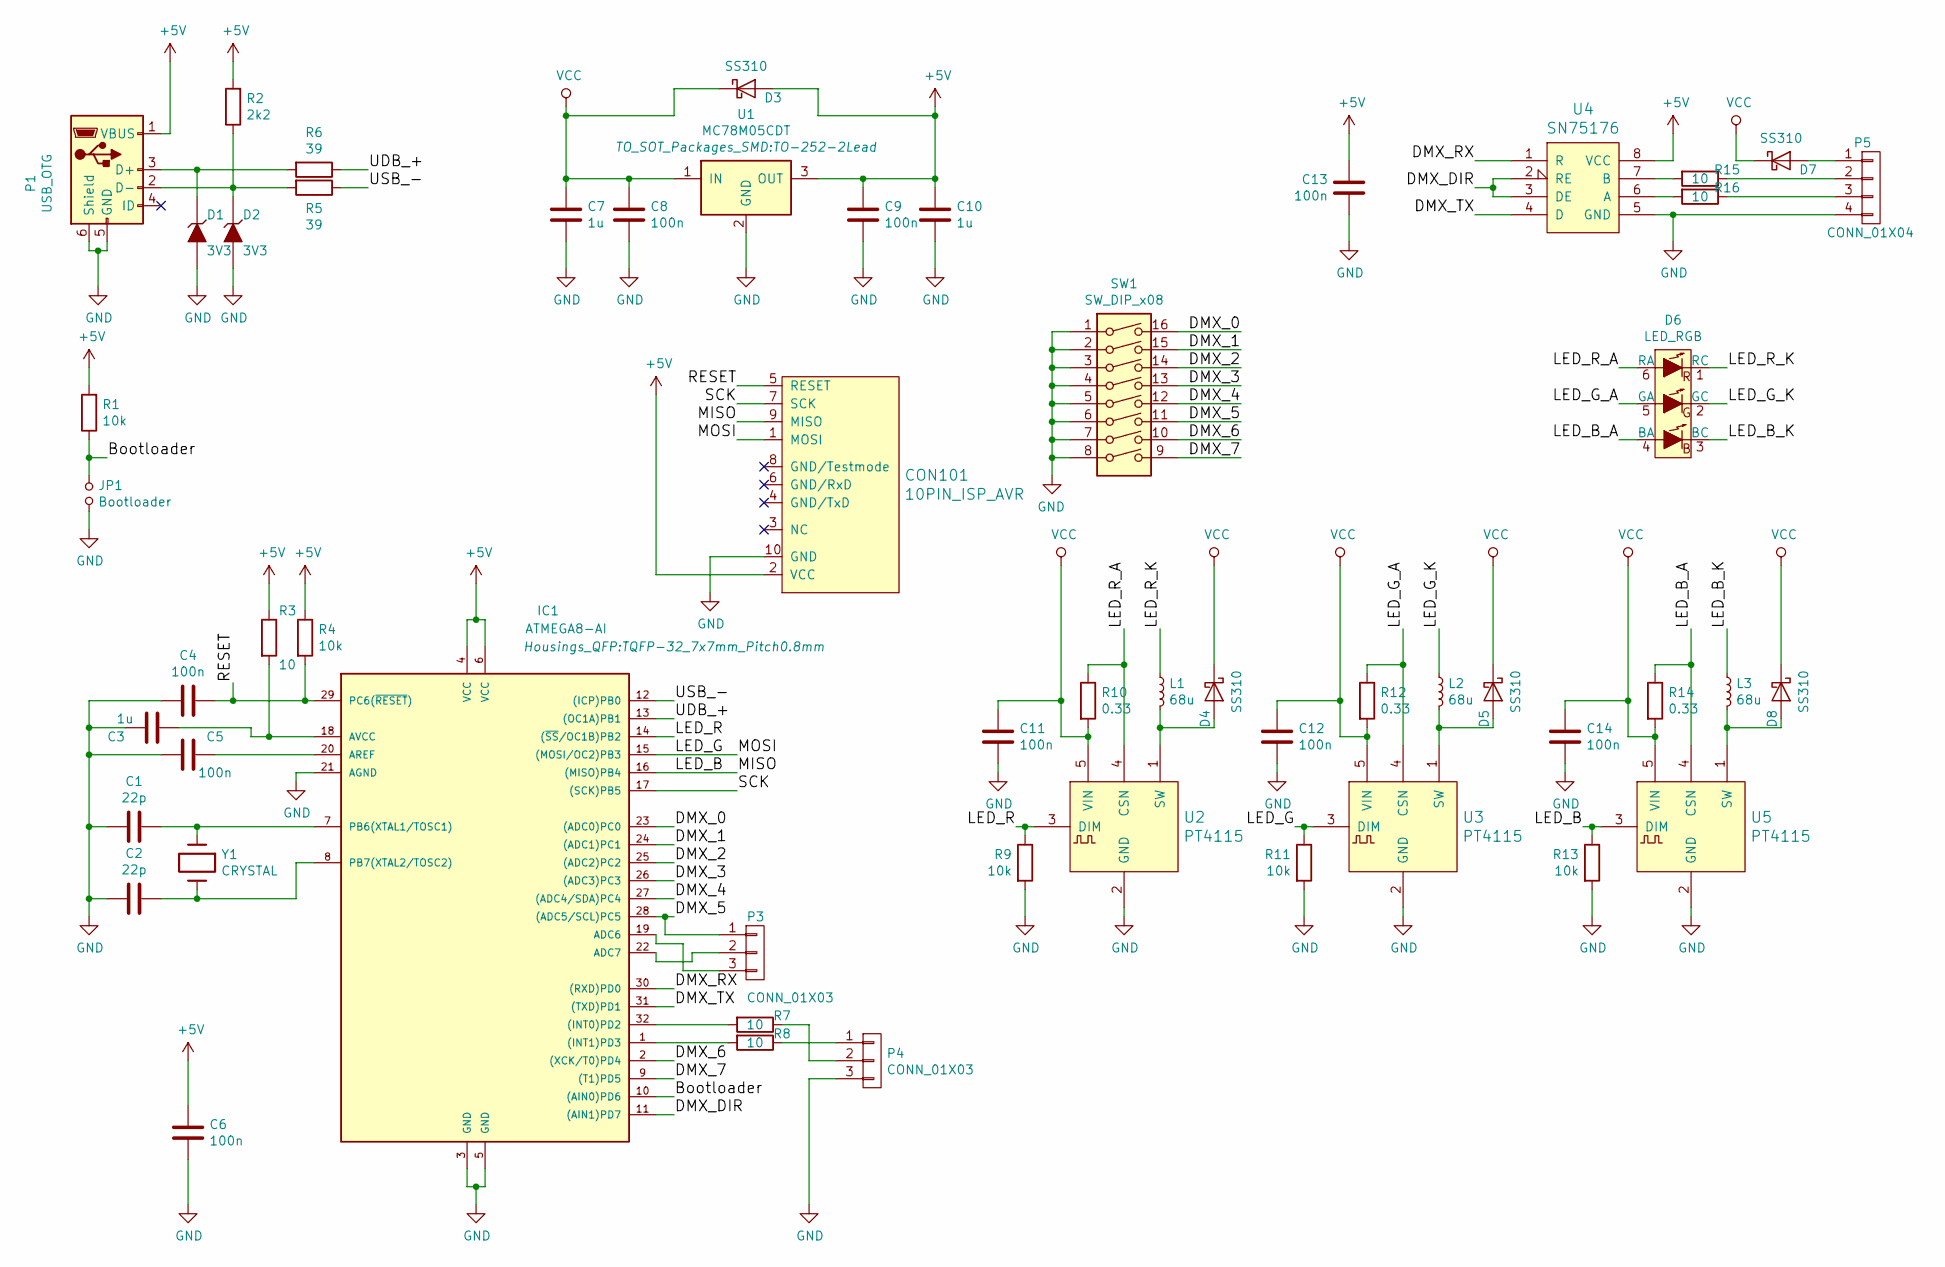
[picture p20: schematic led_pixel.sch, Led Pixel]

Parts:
C1, C2: 22p; C_0603_HandSoldering
C3, C10: 1u; C_0603_HandSoldering
C4, C5, C6, C9, C13: 100n; C_0603_HandSoldering
C7: 1u; C_0805_HandSoldering
C8, C11, C12, C14: 100n; C_0805_HandSoldering
CON101: 10PIN_ISP_AVR; TC2050-IDC
D1, D2: 3V3; D_MiniMELF_Standard
D3, D4, D5, D7, D8: SS310; D_SMA_Standard
D6: LED_RGB; LED_SMD_RGB_3W
IC1: ATMEGA8-AI; TQFP-32_7x7mm_Pitch0.8mm
JP1: Bootloader; Socket_Strip_Straight_1x02
L1, L2, L3: 68u; Choke_SMD_4.5x4x3.2
P1: USB_OTG; USB_Mini-B
P3, P4: CONN_01X03; Socket_Strip_Straight_1x03
P5: CONN_01X04; Socket_Strip_Straight_1x04
R1, R4, R9, R11, R13: 10k; R_0603_HandSoldering
R2: 2k2; R_0603_HandSoldering
R3, R7, R8, R15, R16: 10; R_0603_HandSoldering
R5, R6: 39; R_0603_HandSoldering
R10, R12, R14: 0.33; R_1206_HandSoldering
SW1: SW_DIP_x08; SW_DIP_x8_SMD_2.54
U1: MC78M05CDT; TO-252-2Lead
U2, U3, U5: PT4115; SOT89-5_Housing_Handsoldering
U4: SN75176; SO-8
Y1: CRYSTAL; Crystal_SMD_HC49-SD_HandSoldering

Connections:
+5V: C6.1, C9.1, C10.1, C13.1, CON101.2 (VCC), D3.2 (A), IC1.4 (VCC), IC1.6 (VCC), P1.1 (VBUS), R1.2, R2.2, R3.1, R4.1, U1.3 (OUT), U4.8 (VCC)
/Bootloader: IC1.10 ((AIN0)PD6), JP1.1, R1.1
/DMX_0: IC1.23 ((ADC0)PC0), SW1.16
/DMX_1: IC1.24 ((ADC1)PC1), SW1.15
/DMX_2: IC1.25 ((ADC2)PC2), SW1.14
/DMX_3: IC1.26 ((ADC3)PC3), SW1.13
/DMX_4: IC1.27 ((ADC4/SDA)PC4), SW1.12
/DMX_5: IC1.28 ((ADC5/SCL)PC5), P3.1, SW1.11
/DMX_6: IC1.2 ((XCK/T0)PD4), SW1.10
/DMX_7: IC1.9 ((T1)PD5), SW1.9
/DMX_DIR: IC1.11 ((AIN1)PD7), U4.2 (RE), U4.3 (DE)
/DMX_RX: IC1.30 ((RXD)PD0), U4.1 (R)
/DMX_TX: IC1.31 ((TXD)PD1), U4.4 (D)
/LED_B: CON101.9 (MISO), IC1.16 ((MISO)PB4), R13.1, U5.3 (DIM)
/LED_B_A: D6.4 (BA), R14.1, U5.4 (CSN)
/LED_B_K: D6.3 (BC), L3.1
/LED_G: CON101.1 (MOSI), IC1.15 ((MOSI/OC2)PB3), R11.1, U3.3 (DIM)
/LED_G_A: D6.5 (GA), R12.1, U3.4 (CSN)
/LED_G_K: D6.2 (GC), L2.1
/LED_R: IC1.14 ((~SS~/OC1B)PB2), R9.1, U2.3 (DIM)
/LED_R_A: D6.6 (RA), R10.1, U2.4 (CSN)
/LED_R_K: D6.1 (RC), L1.1
/RESET: C4.1, CON101.5 (RESET), IC1.29 (PC6(~RESET~)), R4.2
/SCK: CON101.7 (SCK), IC1.17 ((SCK)PB5)
/UDB_+: IC1.13 ((OC1A)PB1), R6.1
/USB_-: IC1.12 ((ICP)PB0), R5.1
GND: C1.2, C2.2, C3.2, C4.2, C5.2, C6.2, C7.2, C8.2, C9.2, C10.2, C11.2, C12.2, C13.2, C14.2, CON101.10 (GND), D1.2 (A), D2.2 (A), IC1.3 (GND), IC1.5 (GND), IC1.21 (AGND), JP1.2, P1.5 (GND), P1.6 (Shield), P4.3, P5.4, R9.2, R11.2, R13.2, SW1.1, SW1.2, SW1.3, SW1.4, SW1.5, SW1.6, SW1.7, SW1.8, U1.2 (GND), U2.2 (GND), U3.2 (GND), U4.5 (GND), U5.2 (GND)
unnamed: C1.1, IC1.7 (PB6(XTAL1/TOSC1)), Y1.1
unnamed: C2.1, IC1.8 (PB7(XTAL2/TOSC2)), Y1.2
unnamed: C3.1, IC1.18 (AVCC), R3.2
unnamed: C5.1, IC1.20 (AREF)
unnamed: D1.1 (K), P1.3 (D+), R6.2
unnamed: D2.1 (K), P1.2 (D-), R2.1, R5.2
unnamed: D4.2 (A), L1.2, U2.1 (SW)
unnamed: D5.2 (A), L2.2, U3.1 (SW)
unnamed: D7.2 (A), P5.1
unnamed: D8.2 (A), L3.2, U5.1 (SW)
unnamed: IC1.1 ((INT1)PD3), R8.2
unnamed: IC1.19 (ADC6), P3.3
unnamed: IC1.22 (ADC7), P3.2
unnamed: IC1.32 ((INT0)PD2), R7.2
unnamed: P4.1, R8.1
unnamed: P4.2, R7.1
unnamed: P5.2, R15.1
unnamed: P5.3, R16.1
unnamed: R15.2, U4.7 (B)
unnamed: R16.2, U4.6 (A)
VCC: C7.1, C8.1, C11.1, C12.1, C14.1, D3.1 (K), D4.1 (K), D5.1 (K), D7.1 (K), D8.1 (K), R10.2, R12.2, R14.2, U1.1 (IN), U2.5 (VIN), U3.5 (VIN), U5.5 (VIN)

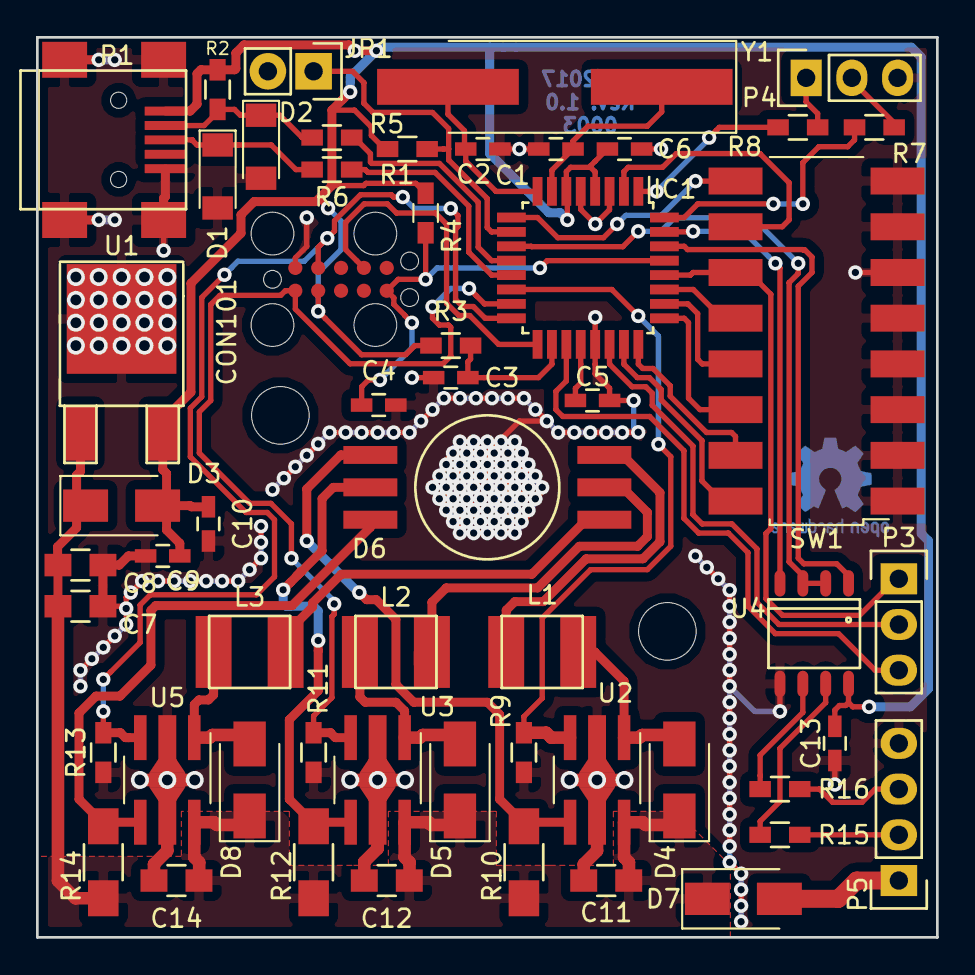
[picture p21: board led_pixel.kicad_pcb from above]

Board: 2 copper layers, 50.0 x 50.0 mm, 55 parts (0 on the bottom side), 48 nets.

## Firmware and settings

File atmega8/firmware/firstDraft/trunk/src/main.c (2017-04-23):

/*
 * main.c
 *
 * Created: 23.04.2017
 *  Author: Prozessorkern
 * 
 * receives a DMX Stream over UART and controls a RGB LED via soft PWM
 *
 */ 
/*
PORTB:

PB0: USB -
PB1: USB +
PB2: LED_R
PB3: LED_G
PB4: LED_B
PB5: NC

PORTC:

PC0: Dip 0
PC1: Dip 1
PC2: Dip 2
PC3: Dip 3
PC4: Dip 4
PC5: Dip 5

PORTD:

PD0: DMX Receive
PD1: DMX Send
PD2: GPIO1
PD3: GPIO2
PD4: Dip 6
PD5: Dip 7
PD6: Bootloader
PD7: DMX_DIR

*/

#define F_CPU 16000000
#define MAX_BRIGHTNES 200

#include <avr/io.h>
#include <util/delay.h>  
#include <avr/interrupt.h> 
#include <stdlib.h>


uint8_t volatile channel[3] = {0,0,0};

int main(void)
{	
	int16_t current_byte = 2;
	uint8_t current_bit = -1;
	int16_t adress;
	int16_t status = 0;
	uint16_t counter = 0;
	uint8_t color = 0;
	uint8_t color_counter = 0;

	DDRB = 0b00011100;
	PORTB = 0b000000000;
	DDRC = 0x00;
	PORTC = 0xFF;
	DDRD = 0b10000010;
	PORTD = 0b00110000;
	
	/*! - enable UART reception */
	UBRRL  = ((F_CPU/4000000)-1);						//250kbaud, 8N2
	UCSRC  = (1<<URSEL)|(3<<UCSZ0)|(1<<USBS);

	UCSRB  = (1<<RXEN);
	
	/*! - configure timer1 */
	TCCR1B = (1<<WGM12)|(1<<CS10);
	OCR1A = 150;
	TIMSK |= (1<<OCIE1A);
	
	/*! - calculate DMX address */
	adress = 256 - (PINC + ((PIND<<2)&0b11000000));

	/*! - reset counter 1 */
	TCNT1 = 0;
	
	/*! - enable interrupts for soft - pwm */
	sei();
	
	while(!(UCSRA & (1<<RXC)))
	{
		counter ++;
		if(counter > 13000)
		{
			counter = 0;
			
			if(color_counter < 255)
			{
				color_counter ++;
			}
			else
			{
				color_counter = 0;
				color ++;
				channel[0] = 0;
				channel[1] = 0;
				channel[2] = 0;
			}
			
			if(!(color & 0x07))
			{
				color ++;
				channel[0] = 0;
				channel[1] = 0;
				channel[2] = 0;
			}
			
			if(color & 0b00000001u)
			{
				channel[0] ++;
			}
			else
			{
				channel[0] = 0u;
			}
			
			if(color & 0b00000010u)
			{
				channel[1] ++;
			}
			else
			{
				channel[1] = 0u;
			}
			
			if(color & 0b00000100u)
			{
				channel[2] ++;
			}
			else
			{
				channel[2] = 0u;
			}

		}			
			
	}
	
	channel[0] = 0;
	channel[1] = 0;
	channel[2] = 0;
	
    while(1)
    {
		/*! - wait for incominc UART Frame (DMX) */
		while(!(UCSRA & (1<<RXC)))
		{
			asm volatile("nop");
		}
		/*! - get status and data from UART controler */
		status = UCSRA;
		current_bit = UDR;
			
		/*! - check for UART framing error ==> DMX pause detected */
		if((status & (1<<FE))){
			current_byte = 1;
			UCSRA &= ~(1<<FE);
		}
		
		/*! - check for first DMX Byte ==> allways 0 */
		else if(current_byte == 1){	
			/* no error */
			if(current_bit == 0)
			{
				current_byte = 2;
			}
			/* error */
			else
			{
				current_byte = -2;
			}	
		}
		
		/*! - check if received DMX date has our address */
		else if(current_byte >= adress && current_byte <=(adress+2)){
			
			/*! - copy data */
			channel[current_byte - adress] = current_bit;
			current_byte ++;
				
		}
		
		/*! - not our address */
		else if(current_byte > 0 && current_byte <= 255)
		{
			current_byte ++;
		}
		
		/*! - DMX address exceeded range ==> stop reception until pause is received */
		else
		{
			current_byte = -2;
		}
		
		/*! - delete UART status */
		UCSRA = 0;
    }
}

/* Timer interrupt handler for soft pwm */
ISR(TIMER1_COMPA_vect){
	
	static uint8_t counter = 0;

	/*! - overflow detected */
	if(counter > 254){
		/*! - reset counter and set outputs if active */
		counter = 0;
		PORTB &= ~((1<<PB2)&(1<<PB3)&(1<<PB4));
		
		if(channel[0] > 0) PORTB |= (1<<PB4);
		if(channel[1] > 0) PORTB |= (1<<PB3);
		if(channel[2] > 0) PORTB |= (1<<PB2);
		
	}
	else{
		/*! - increment counter */
		counter ++;
		
		/*! - reset outputs if nessesary*/
		if(channel[0] < counter) PORTB &= ~(1<<PB4);
		if(channel[1] < counter) PORTB &= ~(1<<PB3);
		if(channel[2] < counter) PORTB &= ~(1<<PB2);
	}

}

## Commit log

2017-02-06 Initial Commit of existing Files
    [led_pixel.kicad_pcb, led_pixel.sch, led_pixel_self_etched.kicad_pcb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]
2017-02-12 layout in process... :|
    [led_pixel.kicad_pcb, led_pixel.sch]
2017-02-20 finished first shot of the layout...
    there are mounting holes missing...
    ...so what ;)
    I hope to find a place for them this week...
    [led_pixel.kicad_pcb, led_pixel.sch]
2017-04-16 finished rought layout with mounting holes and needle debug adaptor...
    [led_pixel.kicad_pcb, led_pixel.sch]
2017-04-16 finished... I hope...
    replaced the ref descriptors...
    [led_pixel.kicad_pcb]
2017-04-16 did some final fixes...
    created doku package and gerber files...
    ready for chinese PCB production ;)
    [led_pixel-B.Cu.gbl, led_pixel-B.Mask.gbs, led_pixel-B.Paste.gbp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]
2017-04-16 ...forget to save layout...
    [led_pixel.kicad_pcb]
2017-04-23 generated documentation and gerber files
    [led_pixel-B.Cu.gbl, led_pixel-B.Mask.gbs, led_pixel-B.Paste.gbp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]
2017-04-23 added a first draft firmware to test some parts of the hardware
    the makefile is crap and has to be improved
    programming is not working right now...
    you will need the avr8 toolchain from Atmel
    [main.c]
2017-04-23 startet with development of stm32f0 powered led pixel
    rough schematics with some of the parts needed
    definition of the backplane bus system is pending
    [led_pixel_stm32f030.kicad_pcb, led_pixel_stm32f030.sch, rgbw_led_driver.sch]
2017-04-30 designed a first draft of the backplane of the dynamic adressing LED Pixels
    started with pcb design of the STM32 version
    [backplane.sch, led_pixel_stm32f030.kicad_pcb, led_pixel_stm32f030.sch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]
2017-05-01 made a first layout draft...
    well okay, wouldn´t call it layout yet ;)
    - next step make it look like a Layout XD
    [backplane.sch, led_pixel_stm32f030.kicad_pcb, led_pixel_stm32f030.sch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]
2017-05-01 added mounting holes
    added a lot of capacitors (there was some room left ;) )
    layout nearly finished
    logos are missing ;)
    not much work left I think
    [led_pixel_stm32f030.kicad_pcb, led_pixel_stm32f030.sch, rgbw_led_driver.sch]
2017-05-07 finished layout for stm32f0 version
    the silkscreen has to be fixed...
    documentation and production data has to be generated
    [led_pixel.kicad_pcb, led_pixel_stm32f030.kicad_pcb]
2017-05-10 hopefully finished everything
    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
    [led_pixel-B.Cu.gbl, led_pixel-B.Mask.gbs, led_pixel-B.SilkS.gbo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]
2017-05-13 added pcb number and revision
    re generated all docu and gerber data
    - ordered this one as rev 1.0
    [led_pixel-B.Cu.gbl, led_pixel-B.Mask.gbs, led_pixel-B.Paste.gbp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]
2017-06-18 updraded to revision V1.1
    Now the cooling pad of the LED is isolated from the ground plane.
    Unfortunately there will be less cooling than before, but the LEDs to use have a stupid connection...
    [backplane.sch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]
2018-12-24 final release of cree led version v1.0
    [backplane.sch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]
2019-08-27 added x4 version
    [led_pixel_stm32f030_x4-B_Cu.gbl, led_pixel_stm32f030_x4-B_Mask.gbs, led_pixel_stm32f030_x4-B_Paste.gbp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]
